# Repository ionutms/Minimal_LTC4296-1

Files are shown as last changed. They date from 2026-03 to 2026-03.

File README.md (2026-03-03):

# Minimal_LTC4296-1

## Overview

This repository contains a minimal KiCad design project for the Analog Devices LTC4296-1, a 5-port SPoE (Single-Pair Power over Ethernet) PSE (Power Sourcing Equipment) controller. The project includes schematic designs and PCB layout files for implementing this versatile multi-port PoE controller.

## Disclaimer

> [!NOTE]
> This project is provided "as is" and without any warranty, express or implied. For more details, please see the [LICENSE](LICENSE) file.

## About the LTC4296-1

The LTC4296-1 from Analog Devices is a 5-port SPoE (Single-Pair Power over Ethernet) PSE controller designed for building and factory automation applications. It provides power sourcing equipment functionality for IEEE 802.3cg-compliant single-pair Ethernet systems.

Key features include:

- **5 Independent PSE Ports:** Controls up to five independent PSE ports with individual monitoring and control.
- **Wide Input Supply Range:** Operates from 6 V to 60 V, supporting both 24 V and 54 V systems.
- **IEEE 802.3cg Compliant:** Supports Single-Pair Power over Ethernet (SPoE) standard with power classes 10 through 15.
- **SCCP Support:** Supports Serial Communication Classification Protocol (SCCP) with external microcontroller for PD classification.
- **SPI Interface:** SPI bus interface with PEC (Packet Error Code) protection for digital control and monitoring.
- **Advanced Protection:** Features adjustable source and return electronic circuit breakers, high-side circuit breakers with foldback, and analog current limit (ACL).
- **Low Power Consumption:** Ultra-low input supply current of 52 μA (typ) in sleep state and 51 μA (typ) in disabled state.
- **Telemetry:** Voltage, current, and temperature telemetry with per-port power-good comparators.
- **Operating Temperature Range:** -40°C to +125°C.
- **Package:** Available in a 48-lead plastic QFN package (7 mm × 7 mm).

## Project Structure

```
minimal_ltc4296-1/
├── minimal_ltc4296-1.kicad_pro                     # Project configuration file
├── minimal_ltc4296-1.kicad_sch                     # Main schematic file
├── SCCP Circuit 0.kicad_sch                        # SCCP circuit schematic
├── minimal_ltc4296-1.kicad_pcb                     # PCB layout file
├── fp-lib-table                                    # Footprint library table
├── sym-lib-table                                   # Symbol library table
├── docs/                                           # Documentation files
│   ├── bom/                                        # Bill of Materials
│   │   └── minimal_ltc4296-1_ibom.html             # Interactive BOM file
│   ├── pictures/                                   # Images and photos
│   │   ├── 1_minimal_ltc4296-1_side.png            # Side view of PCB
│   │   ├── 2_minimal_ltc4296-1_top.png             # Top view of PCB
│   │   ├── 3_minimal_ltc4296-1_bottom.png          # Bottom view of PCB
│   │   ├── 4_minimal_ltc4296-1_left.png            # Left view of PCB
│   │   ├── 5_minimal_ltc4296-1_right.png           # Right view of PCB
│   │   ├── 6_minimal_ltc4296-1_front.png           # Front view of PCB
│   │   ├── 7_minimal_ltc4296-1_back.png            # Back view of PCB
│   │   └── 8_minimal_ltc4296-1_test.png            # Test view of PCB
│   └── schematics/                                 # Schematic PDF exports
│       └── minimal_ltc4296-1_schematics.pdf        # Complete schematics PDF
└── KiCAD_Symbols_Generator/                        # Submodule for symbol generation from CSV data
```

## Project Features

This design provides a minimal implementation of the LTC4296-1 with:

- 5-port PSE controller configuration
- SPI interface for digital control
- SCCP classification support
- Per-port current monitoring and protection
- Standard footprint for the 48-lead QFN package

## Getting Started

### Prerequisites

- [KiCad EDA](https://www.kicad.org/) version 9.0 or later installed on your system
- Git (for cloning the repository and submodule management)

### Opening the Project

1. **Clone the repository** (including submodules):
   ```bash
   git clone --recursive https://github.com/ionutms/Minimal_LTC4296-1.git
   ```

   If you've already cloned the repository without submodules, initialize them with:
   ```bash
   git submodule init
   git submodule update
   ```

2. **Open the project in KiCad**:
   - Launch KiCad
   - Click "Open Existing Project"
   - Navigate to the cloned repository folder
   - Select the `minimal_ltc4296-1.kicad_pro` file

3. **Explore the design**:
   - Open the schematic editor to view the circuit design
   - Open the PCB editor to view the board layout
   - Review the symbol and footprint libraries used in the design

### Project Files

- **Main schematic**: `minimal_ltc4296-1.kicad_sch` - Contains the primary circuit design with the LTC4296-1 and support components
- **SCCP schematic**: `SCCP Circuit 0.kicad_sch` - SCCP circuit implementation for PD classification
- **PCB layout**: `minimal_ltc4296-1.kicad_pcb` - Physical board design file with proper component placement
- **Project configuration**: `minimal_ltc4296-1.kicad_pro` - KiCad project settings

## Dependencies

This project has the following dependencies:

### 1. KiCAD Symbols Generator

This repository uses [KiCAD_Symbols_Generator](https://github.com/ionutms/KiCAD_Symbols_Generator) as a submodule for custom symbol generation.

To initialize the submodule after cloning this repository:

```bash
git submodule update --init --recursive
```

### 2. 3D Models

This project requires the [3D_Models_Vault](https://github.com/ionutms/3D_Models_Vault) repository for 3D models.

#### Setup for KiCAD 9:

1. Clone the 3D models repository:
   ```bash
   git clone https://github.com/ionutms/3D_Models_Vault.git
   ```

2. In KiCAD 9, add an environment variable:
   - Variable name: `KICAD9_3D_MODELS_VAULT`
   - Variable value: Full path to where you cloned the 3D_Models_Vault repository

## Usage

After setting up the dependencies, open the project in KiCad 9 to access all features including the 3D models.

## Symbol Generator Submodule

This project includes the KiCAD_Symbols_Generator as a submodule, which provides tools for generating KiCad symbols from CSV data files. For more information on using this tool, see the [KiCAD_Symbols_Generator documentation](minimal_ltc4296-1/KiCAD_Symbols_Generator/README.md).

## Documentation

The `docs` folder contains:
- Schematic PDF exports
- Images and photos of the design

## Visuals

The following images showcase the PCB design from different perspectives:

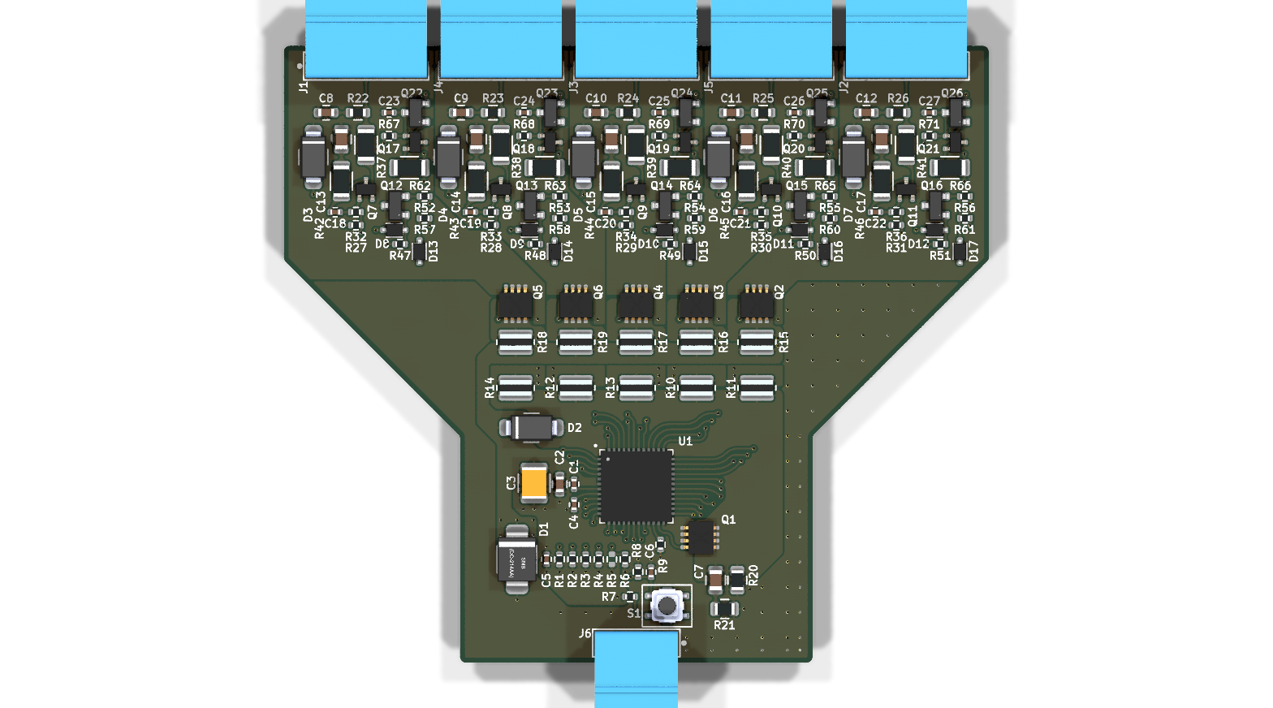
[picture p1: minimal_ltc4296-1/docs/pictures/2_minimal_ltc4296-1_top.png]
Top View

*Top View of the PCB*

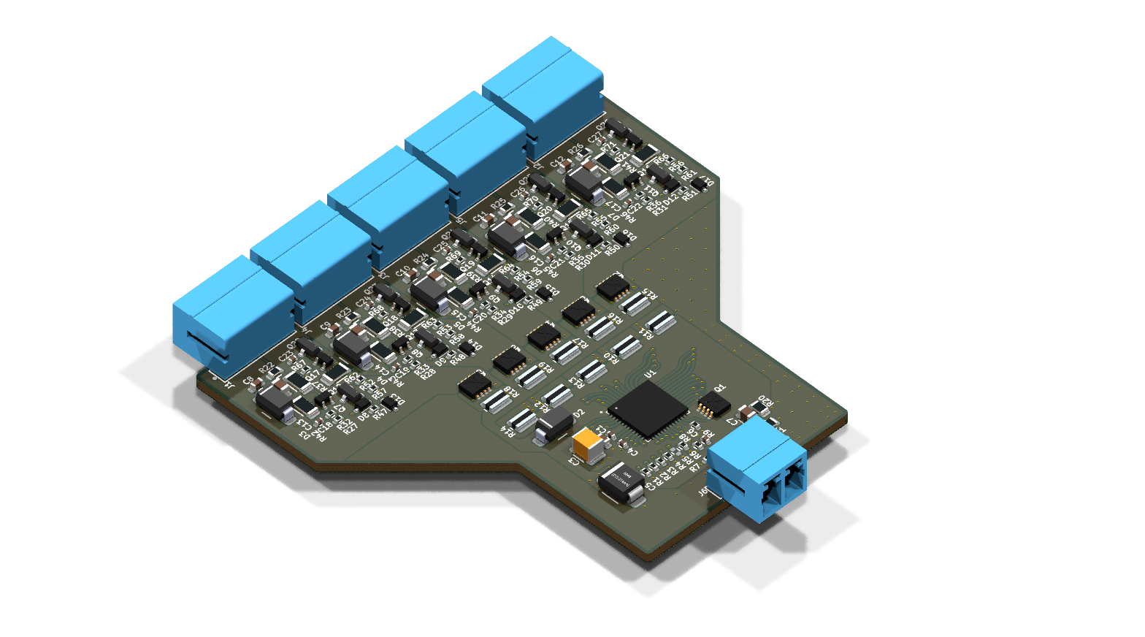
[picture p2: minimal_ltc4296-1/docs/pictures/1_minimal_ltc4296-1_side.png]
Side View

*Side View of the PCB*

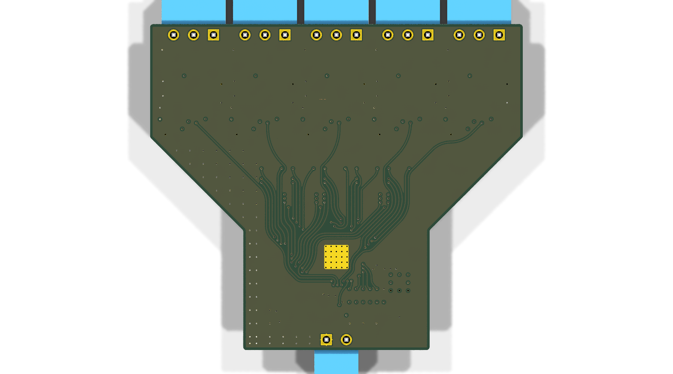
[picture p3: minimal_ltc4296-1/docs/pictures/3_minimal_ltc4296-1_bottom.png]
Bottom View

*Bottom View of the PCB*

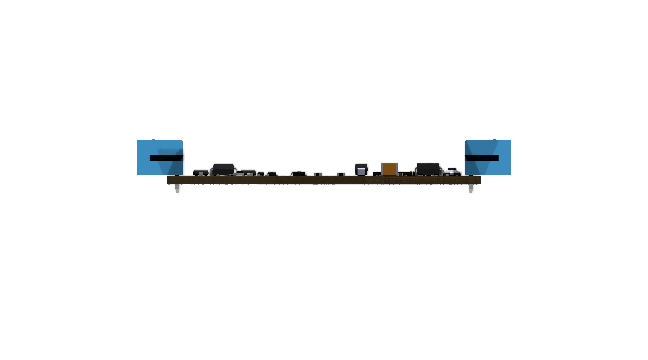
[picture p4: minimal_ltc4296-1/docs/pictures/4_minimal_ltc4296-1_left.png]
Left View

*Left View of the PCB*

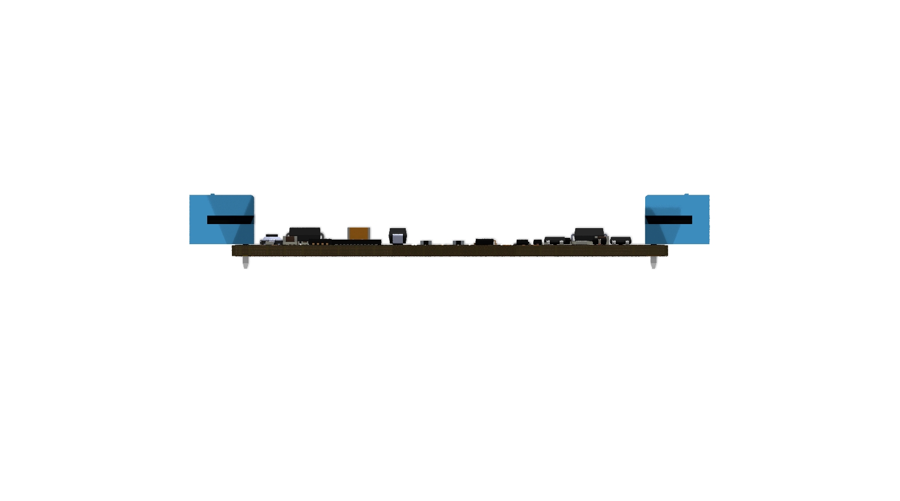
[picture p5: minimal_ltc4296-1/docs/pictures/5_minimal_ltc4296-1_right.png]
Right View

*Right View of the PCB*

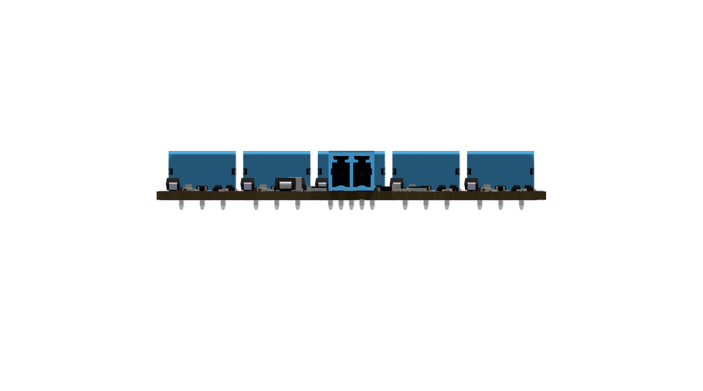
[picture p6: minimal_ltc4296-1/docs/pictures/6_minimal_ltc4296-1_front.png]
Front View

*Front View of the PCB*

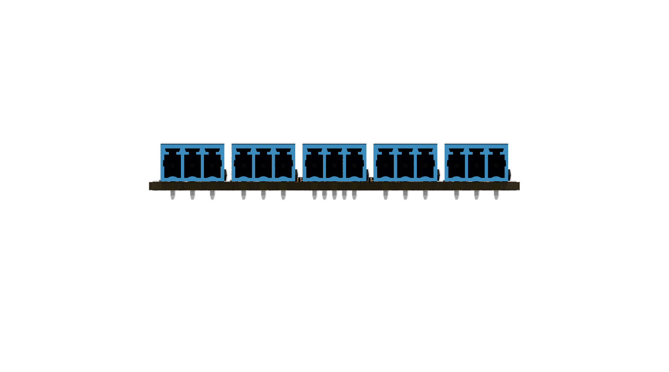
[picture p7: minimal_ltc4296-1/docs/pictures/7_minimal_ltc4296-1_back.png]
Back View

*Back View of the PCB*

## License

This project is licensed under the MIT License - see the [LICENSE](LICENSE) file for details.

## References

- [LTC4296-1 Datasheet](https://www.analog.com/media/en/technical-documentation/data-sheets/ltc4296-1.pdf)
- [LTC4296-1 Product Page](https://www.analog.com/en/products/ltc4296-1.html)
- [KiCad EDA](https://www.kicad.org/)

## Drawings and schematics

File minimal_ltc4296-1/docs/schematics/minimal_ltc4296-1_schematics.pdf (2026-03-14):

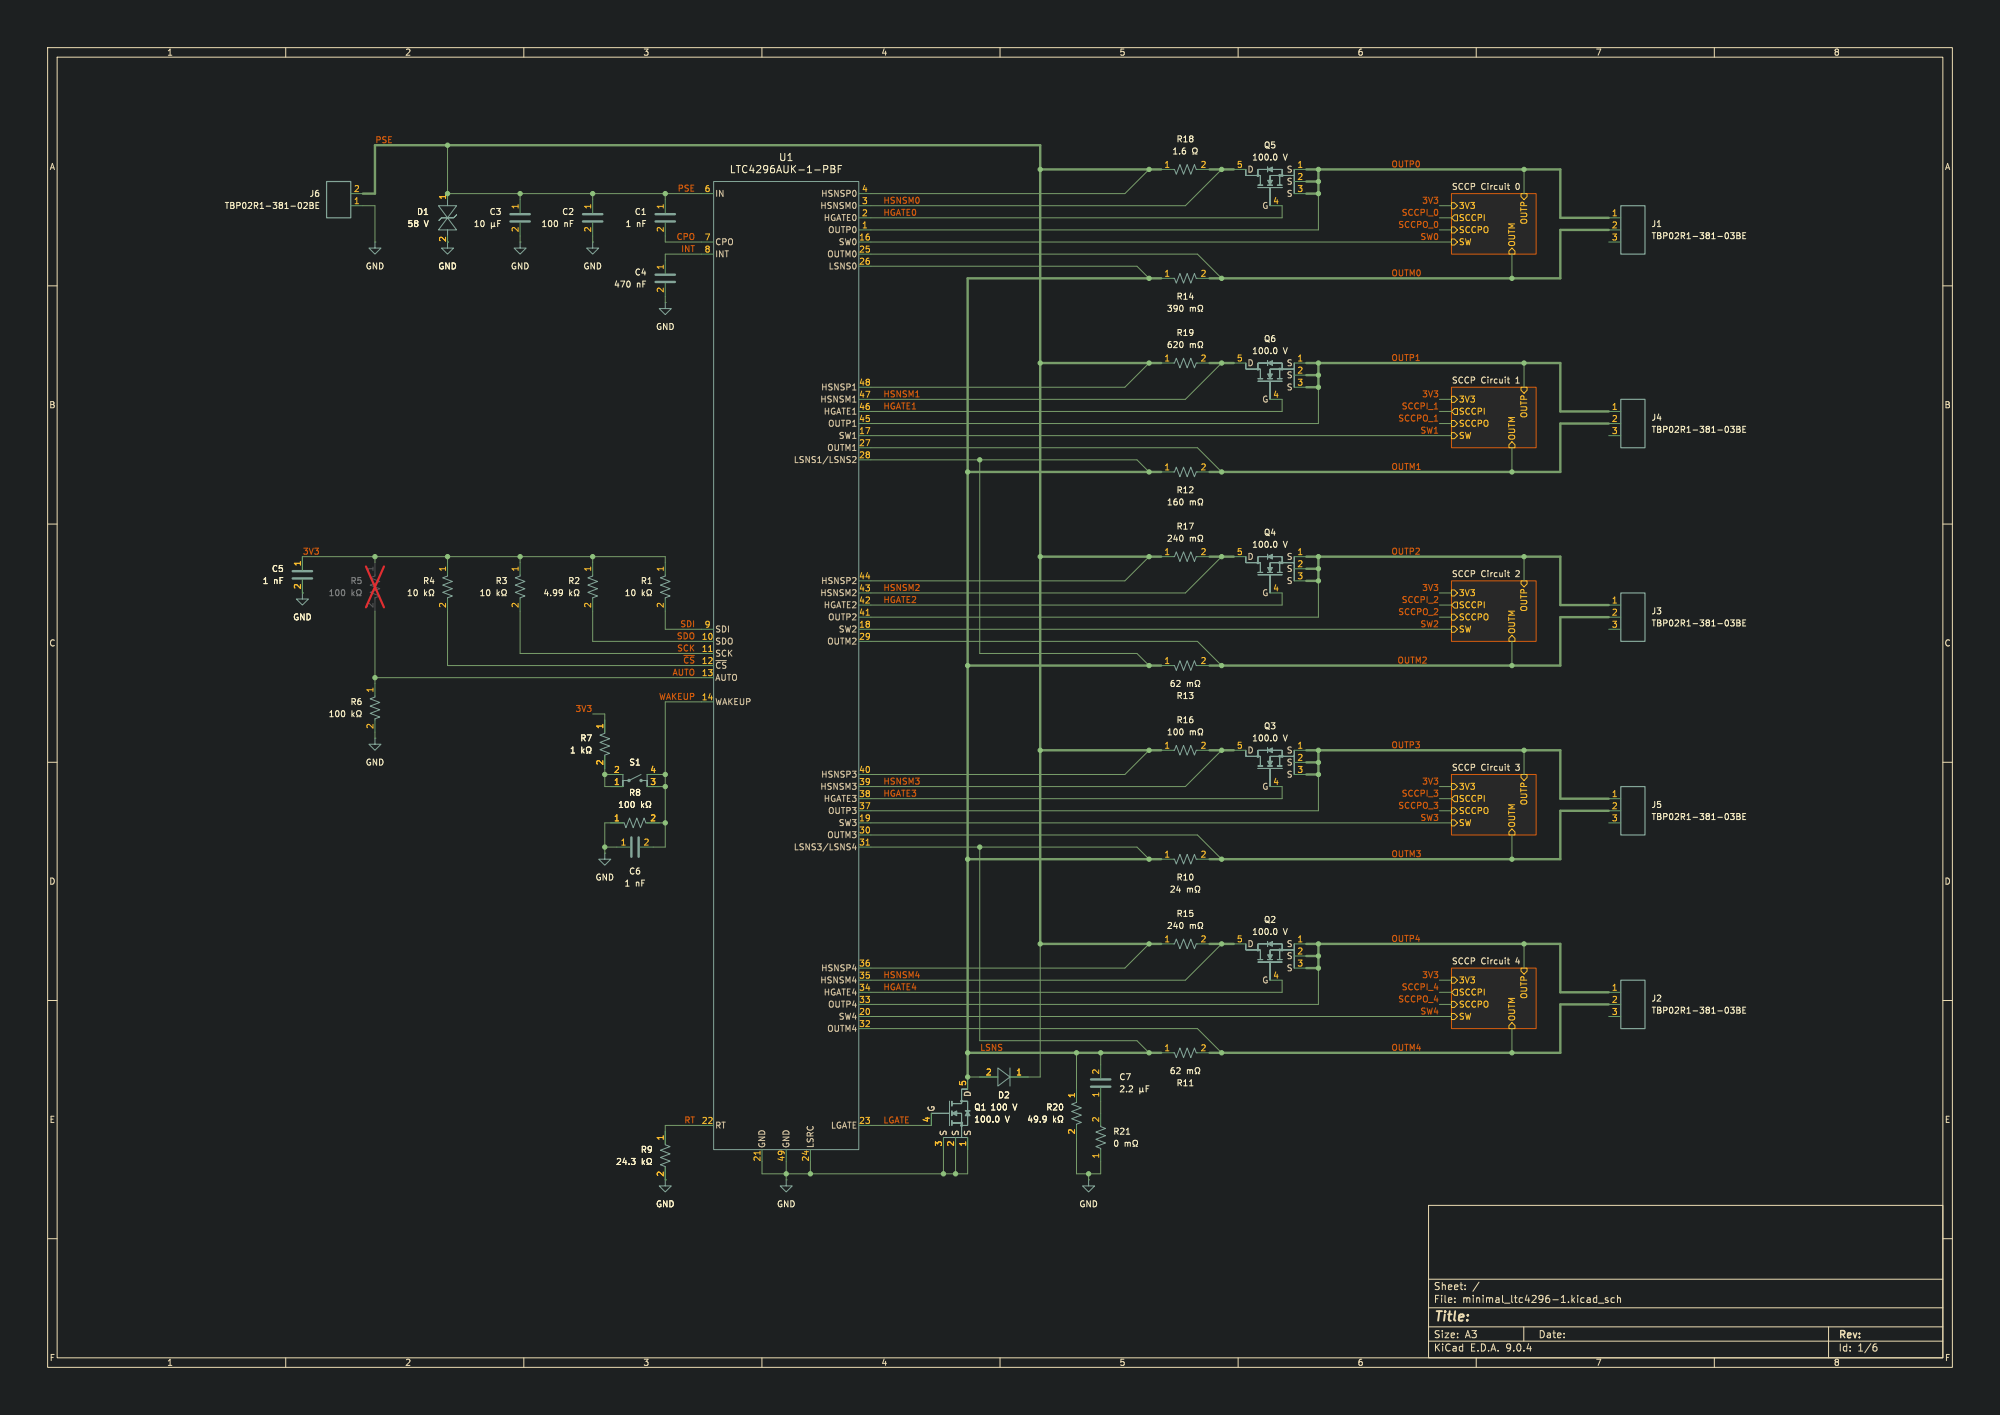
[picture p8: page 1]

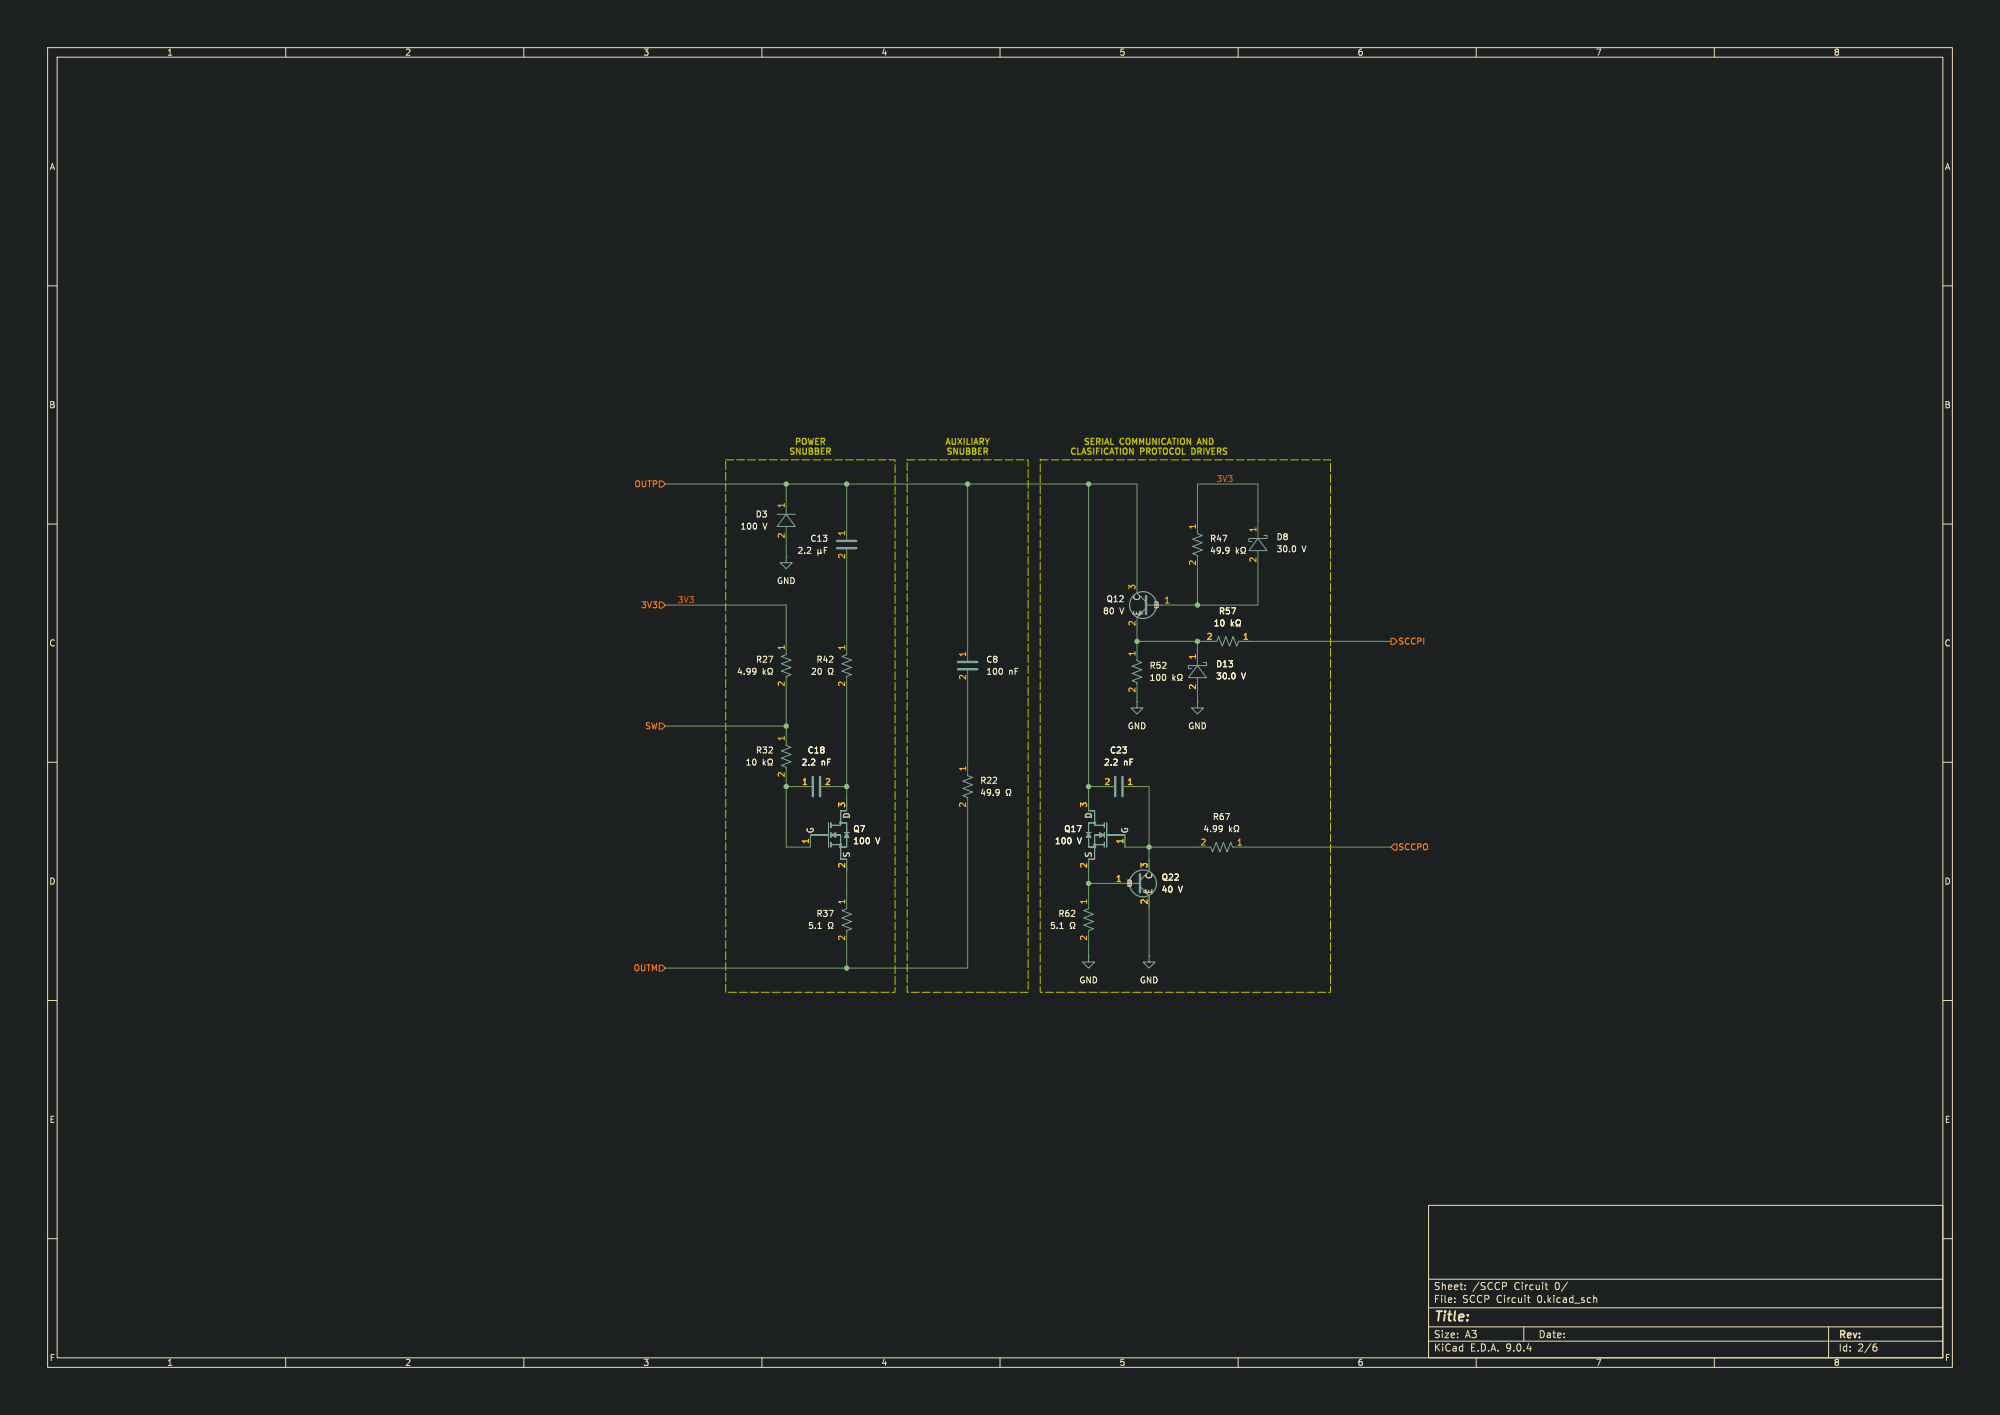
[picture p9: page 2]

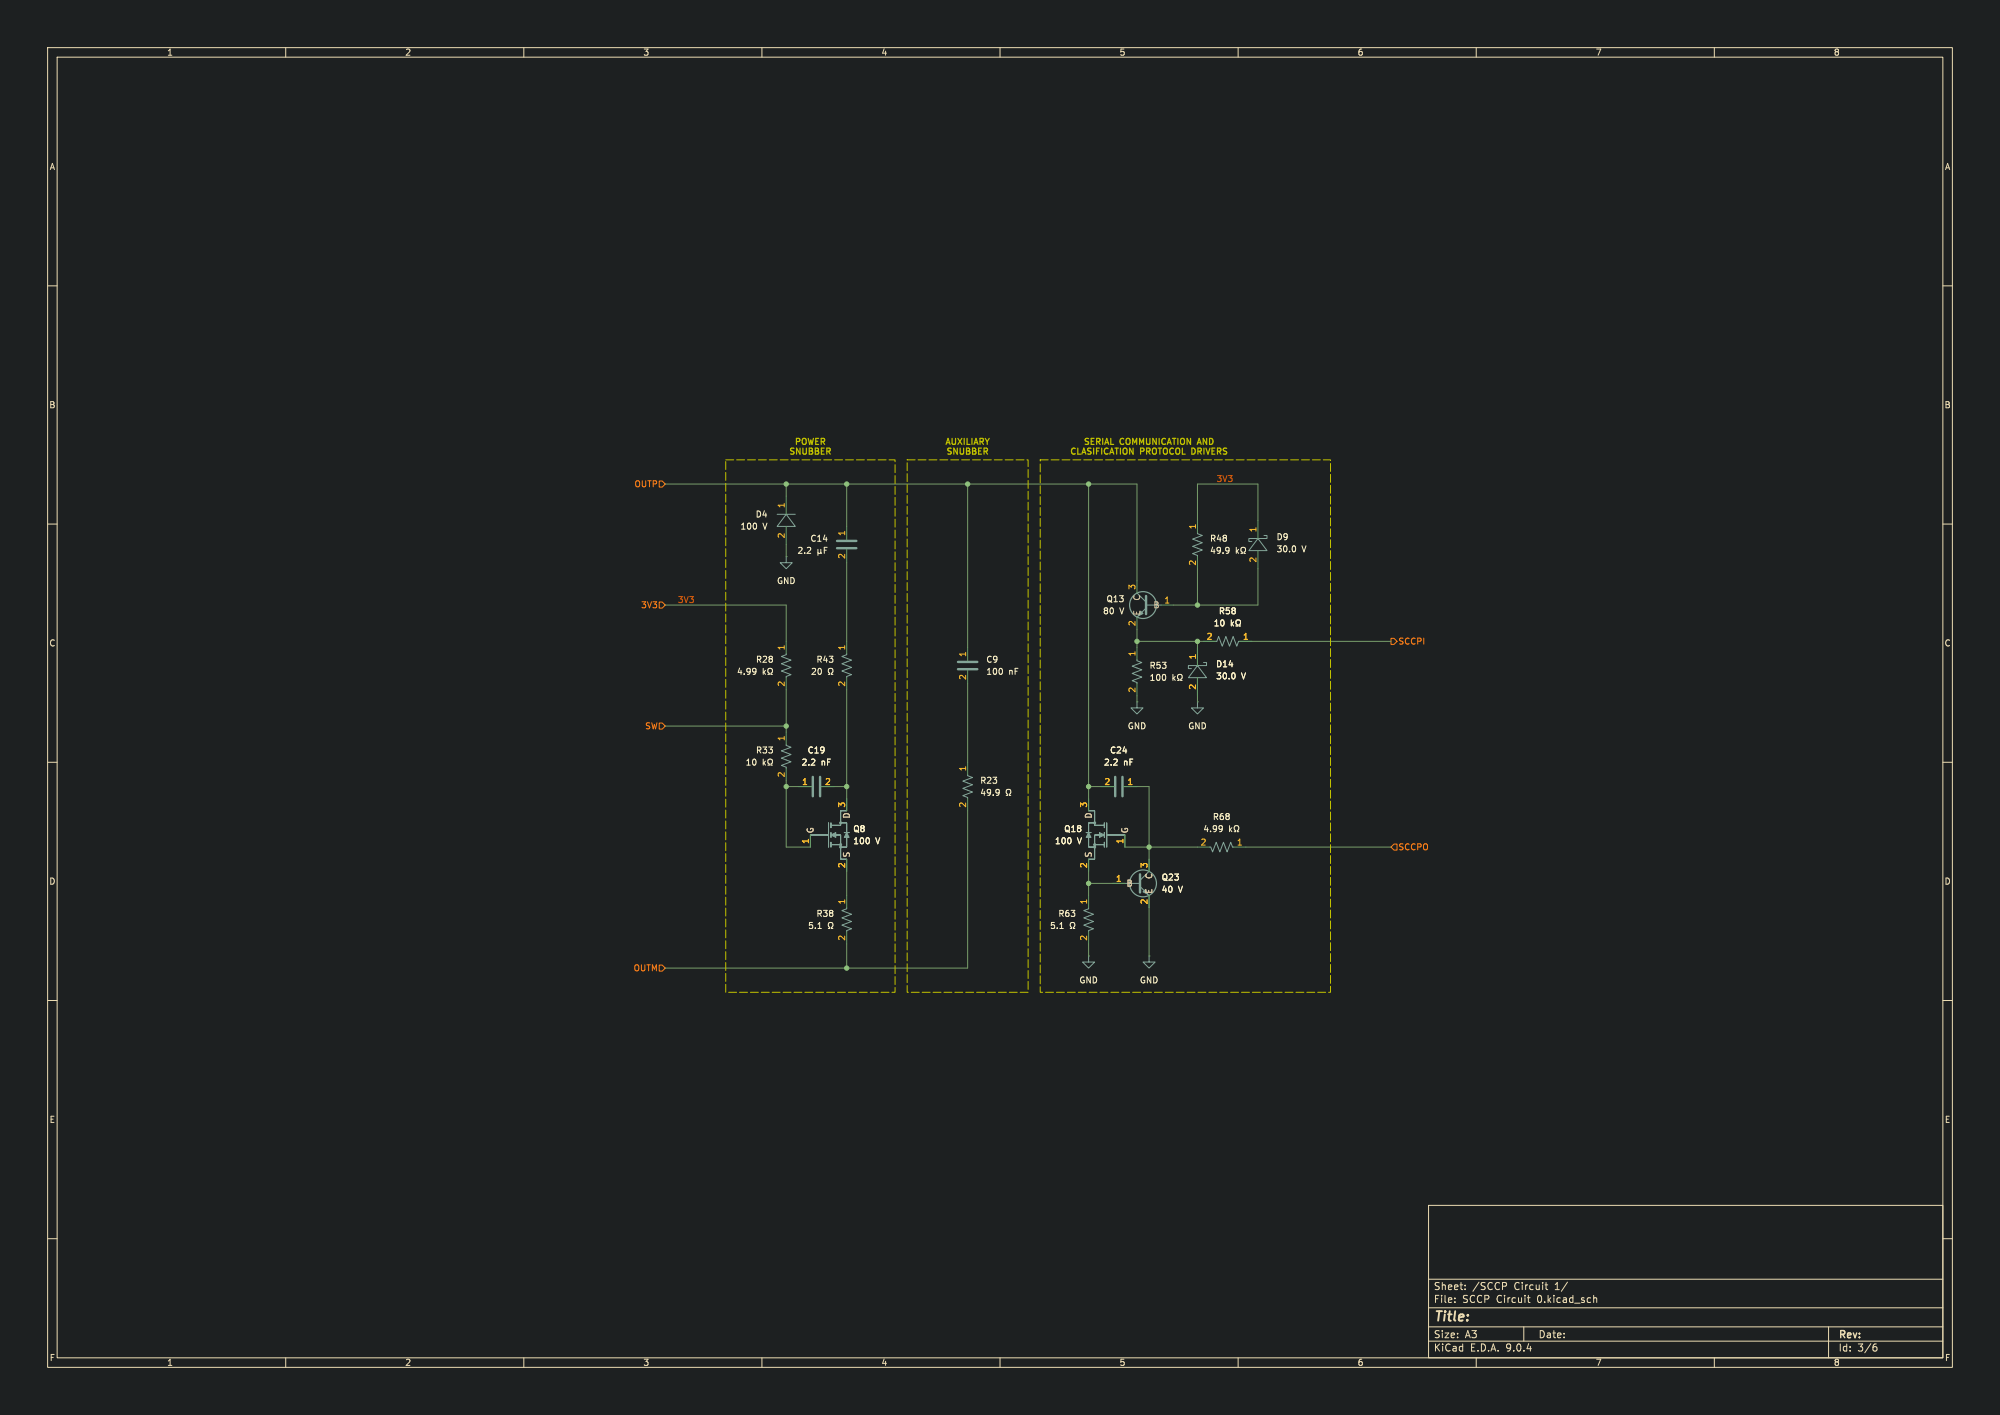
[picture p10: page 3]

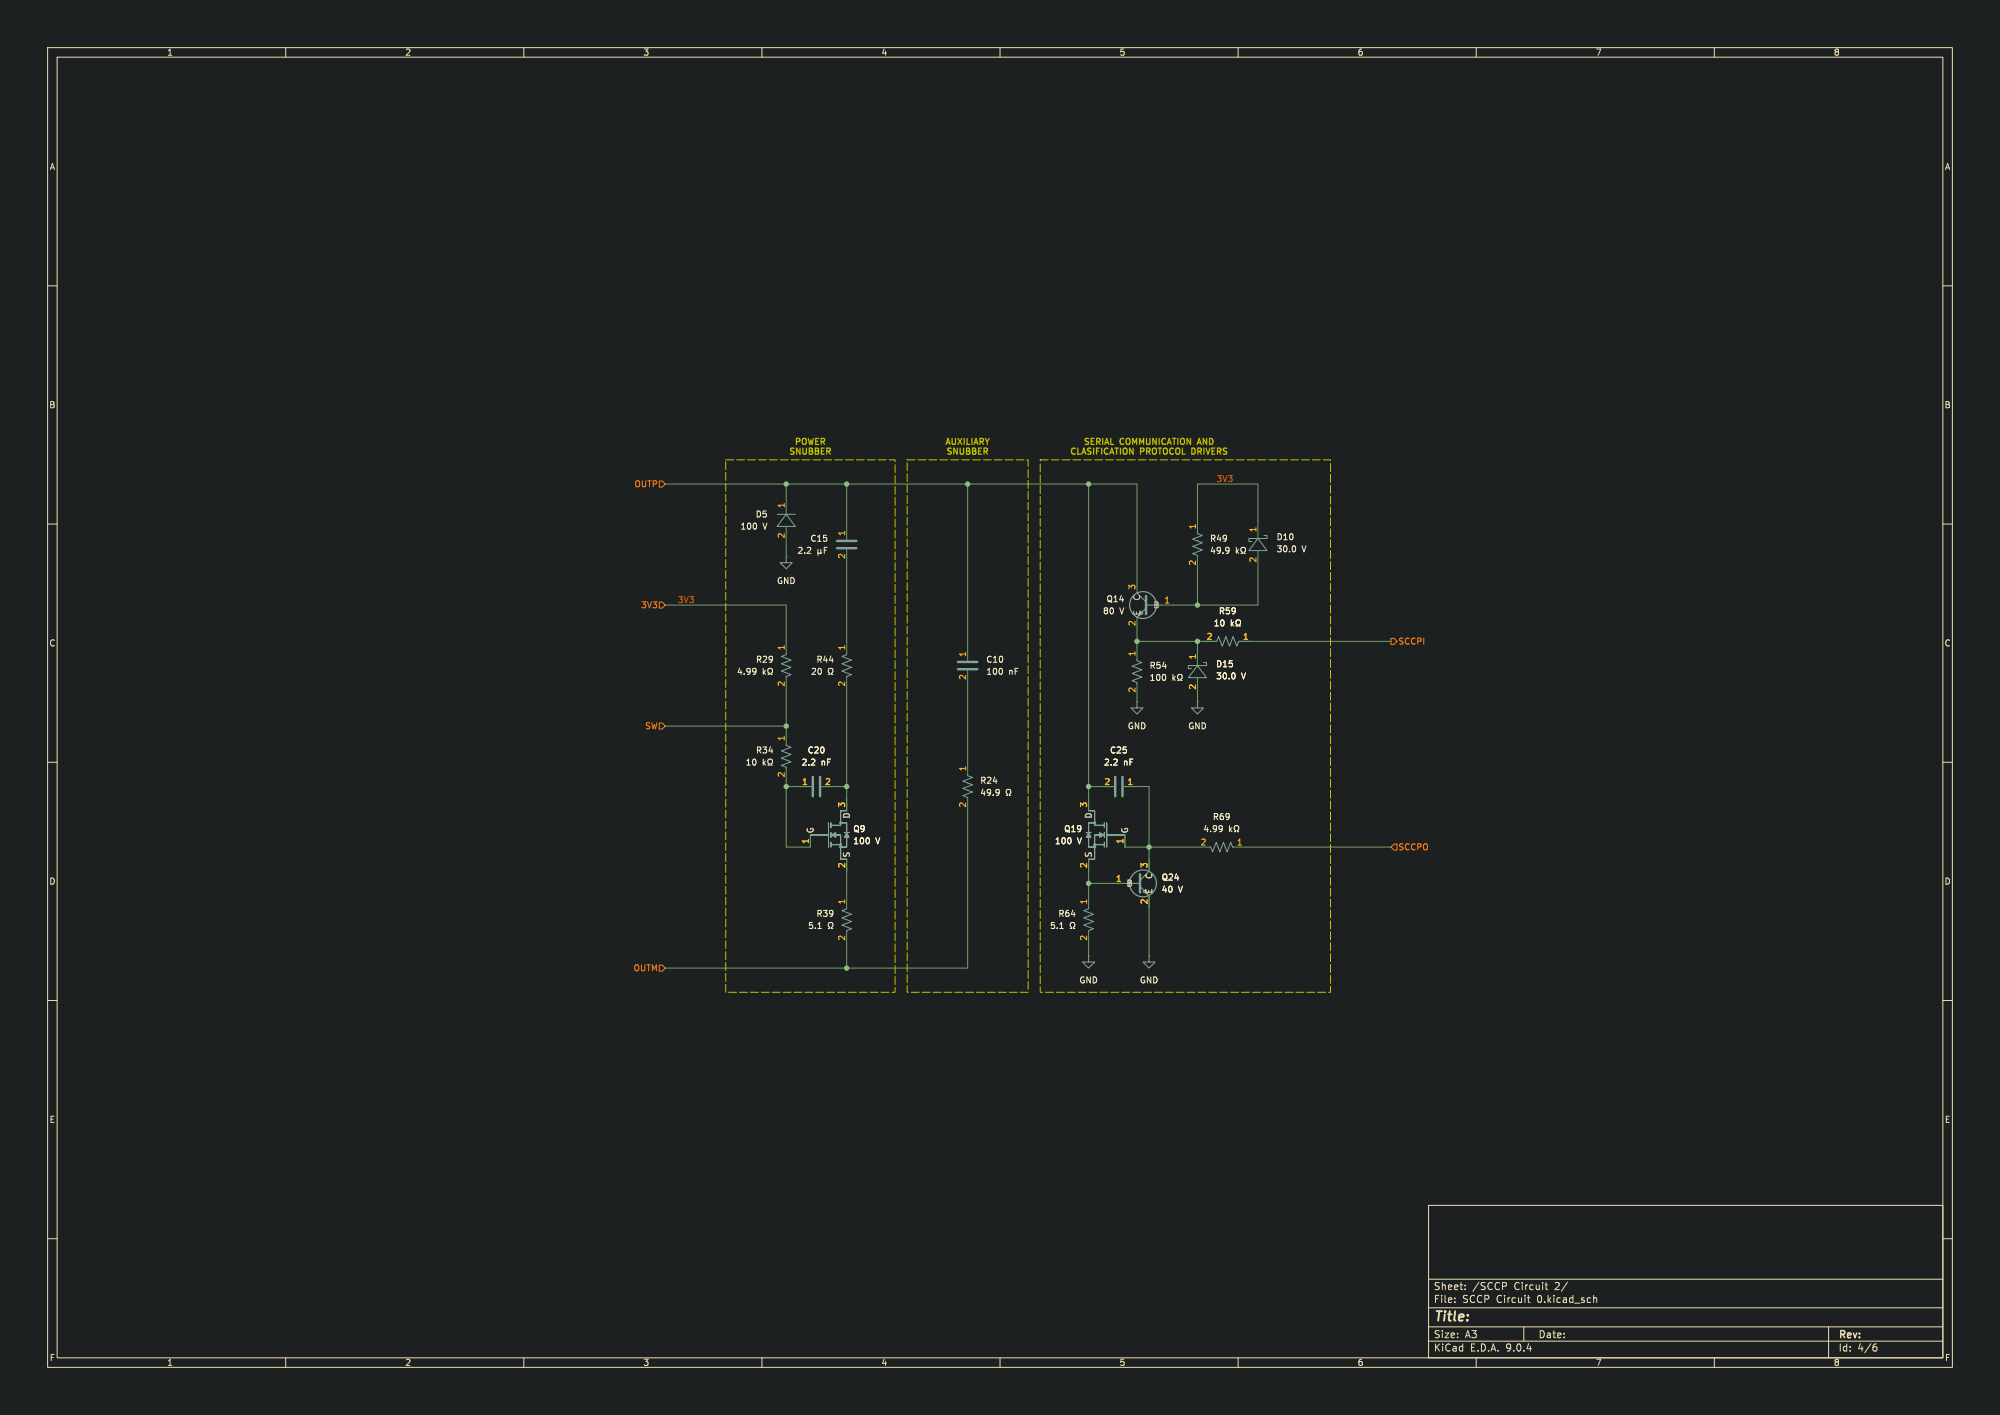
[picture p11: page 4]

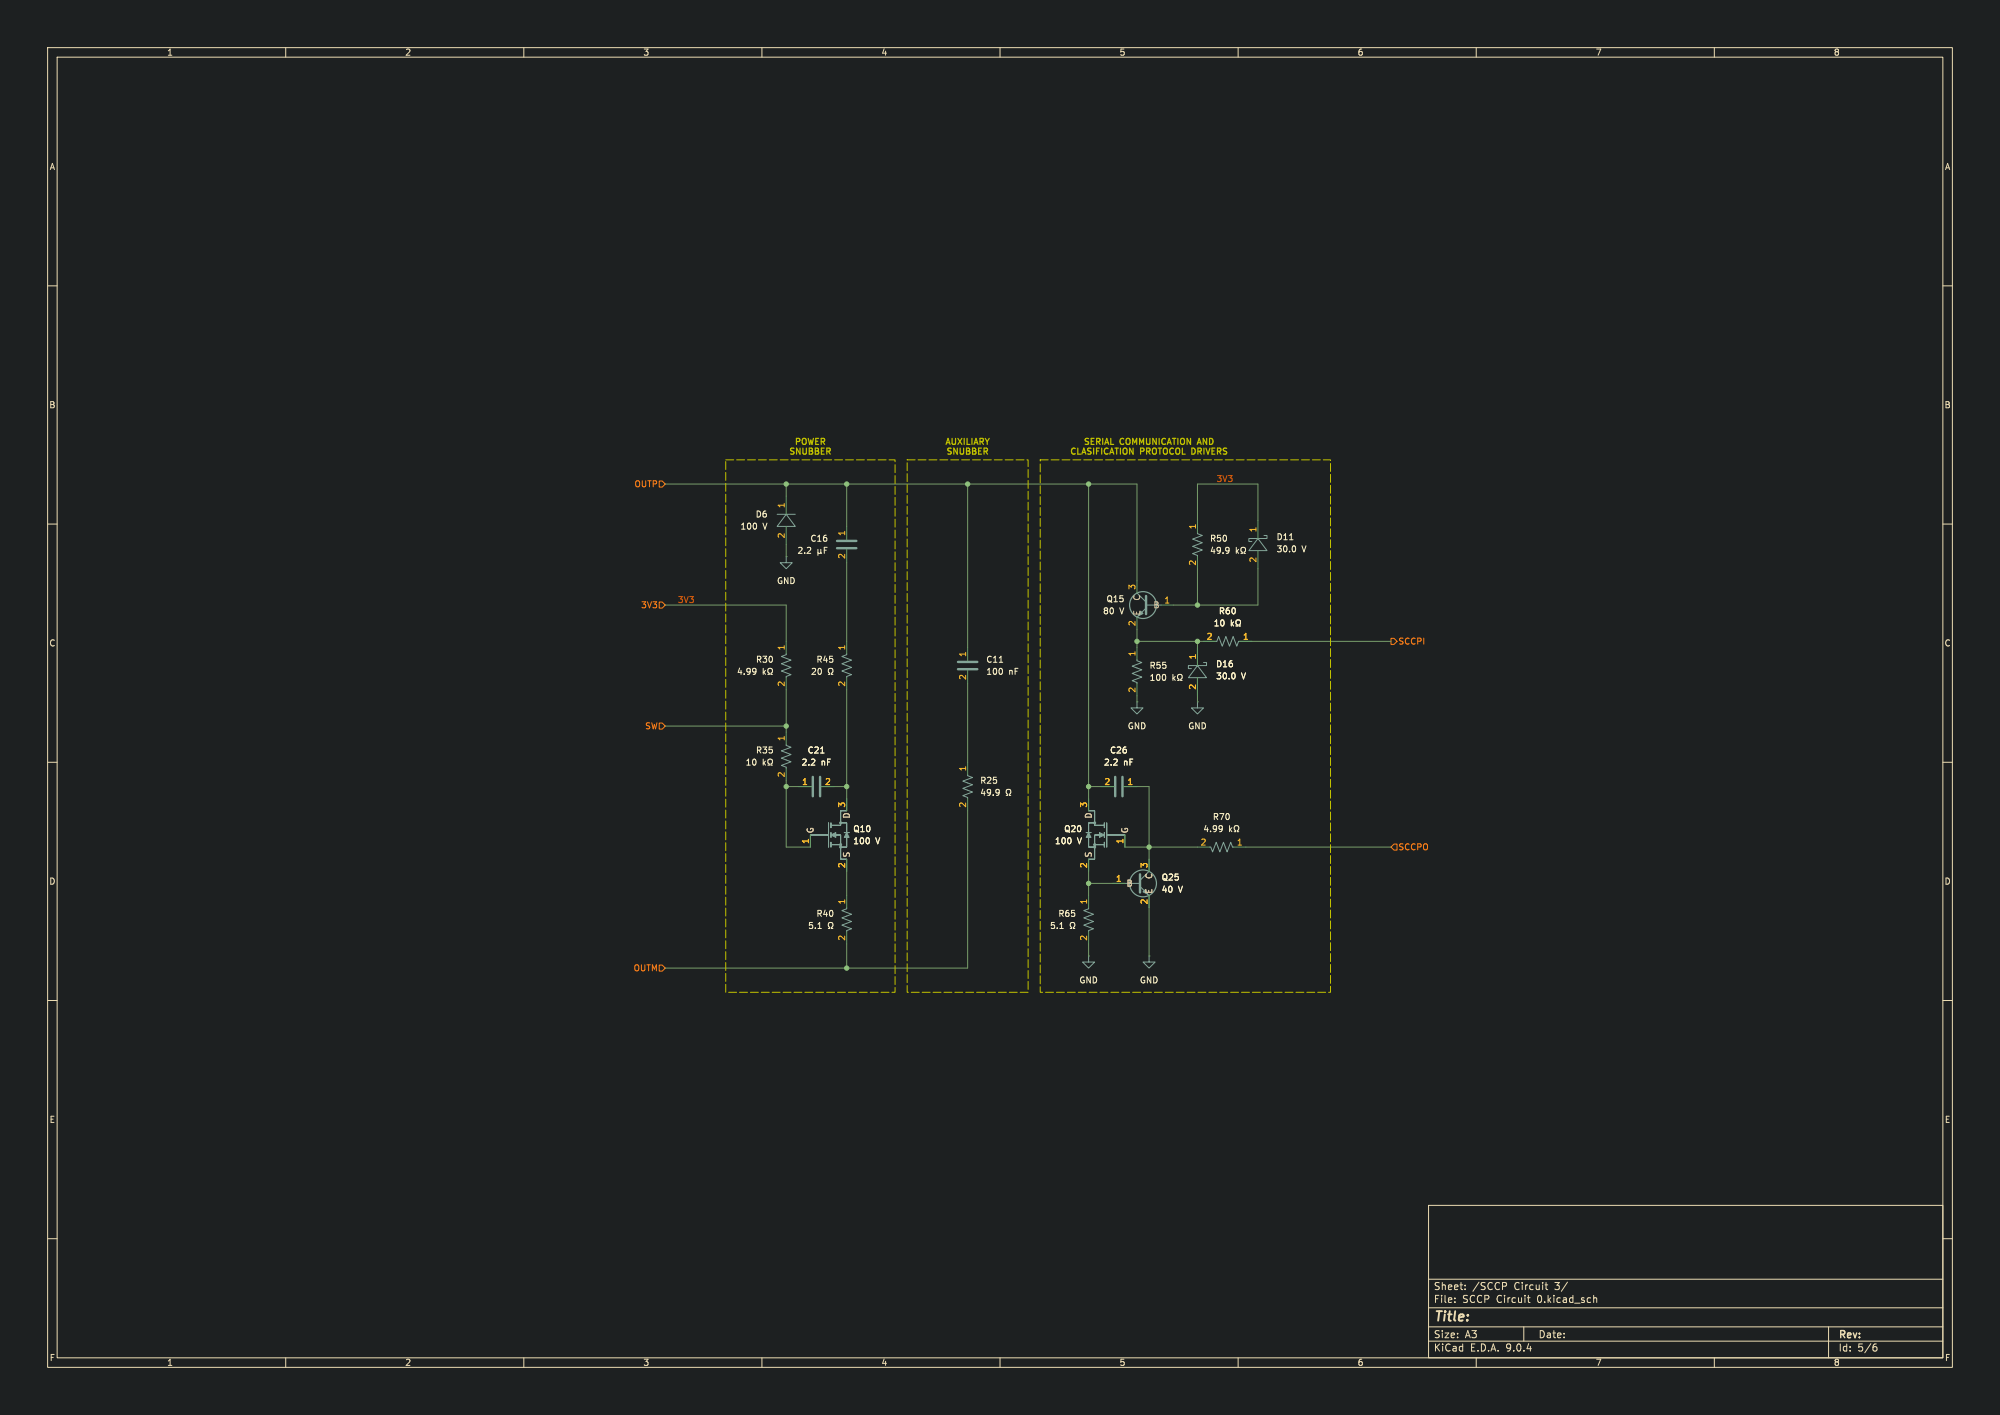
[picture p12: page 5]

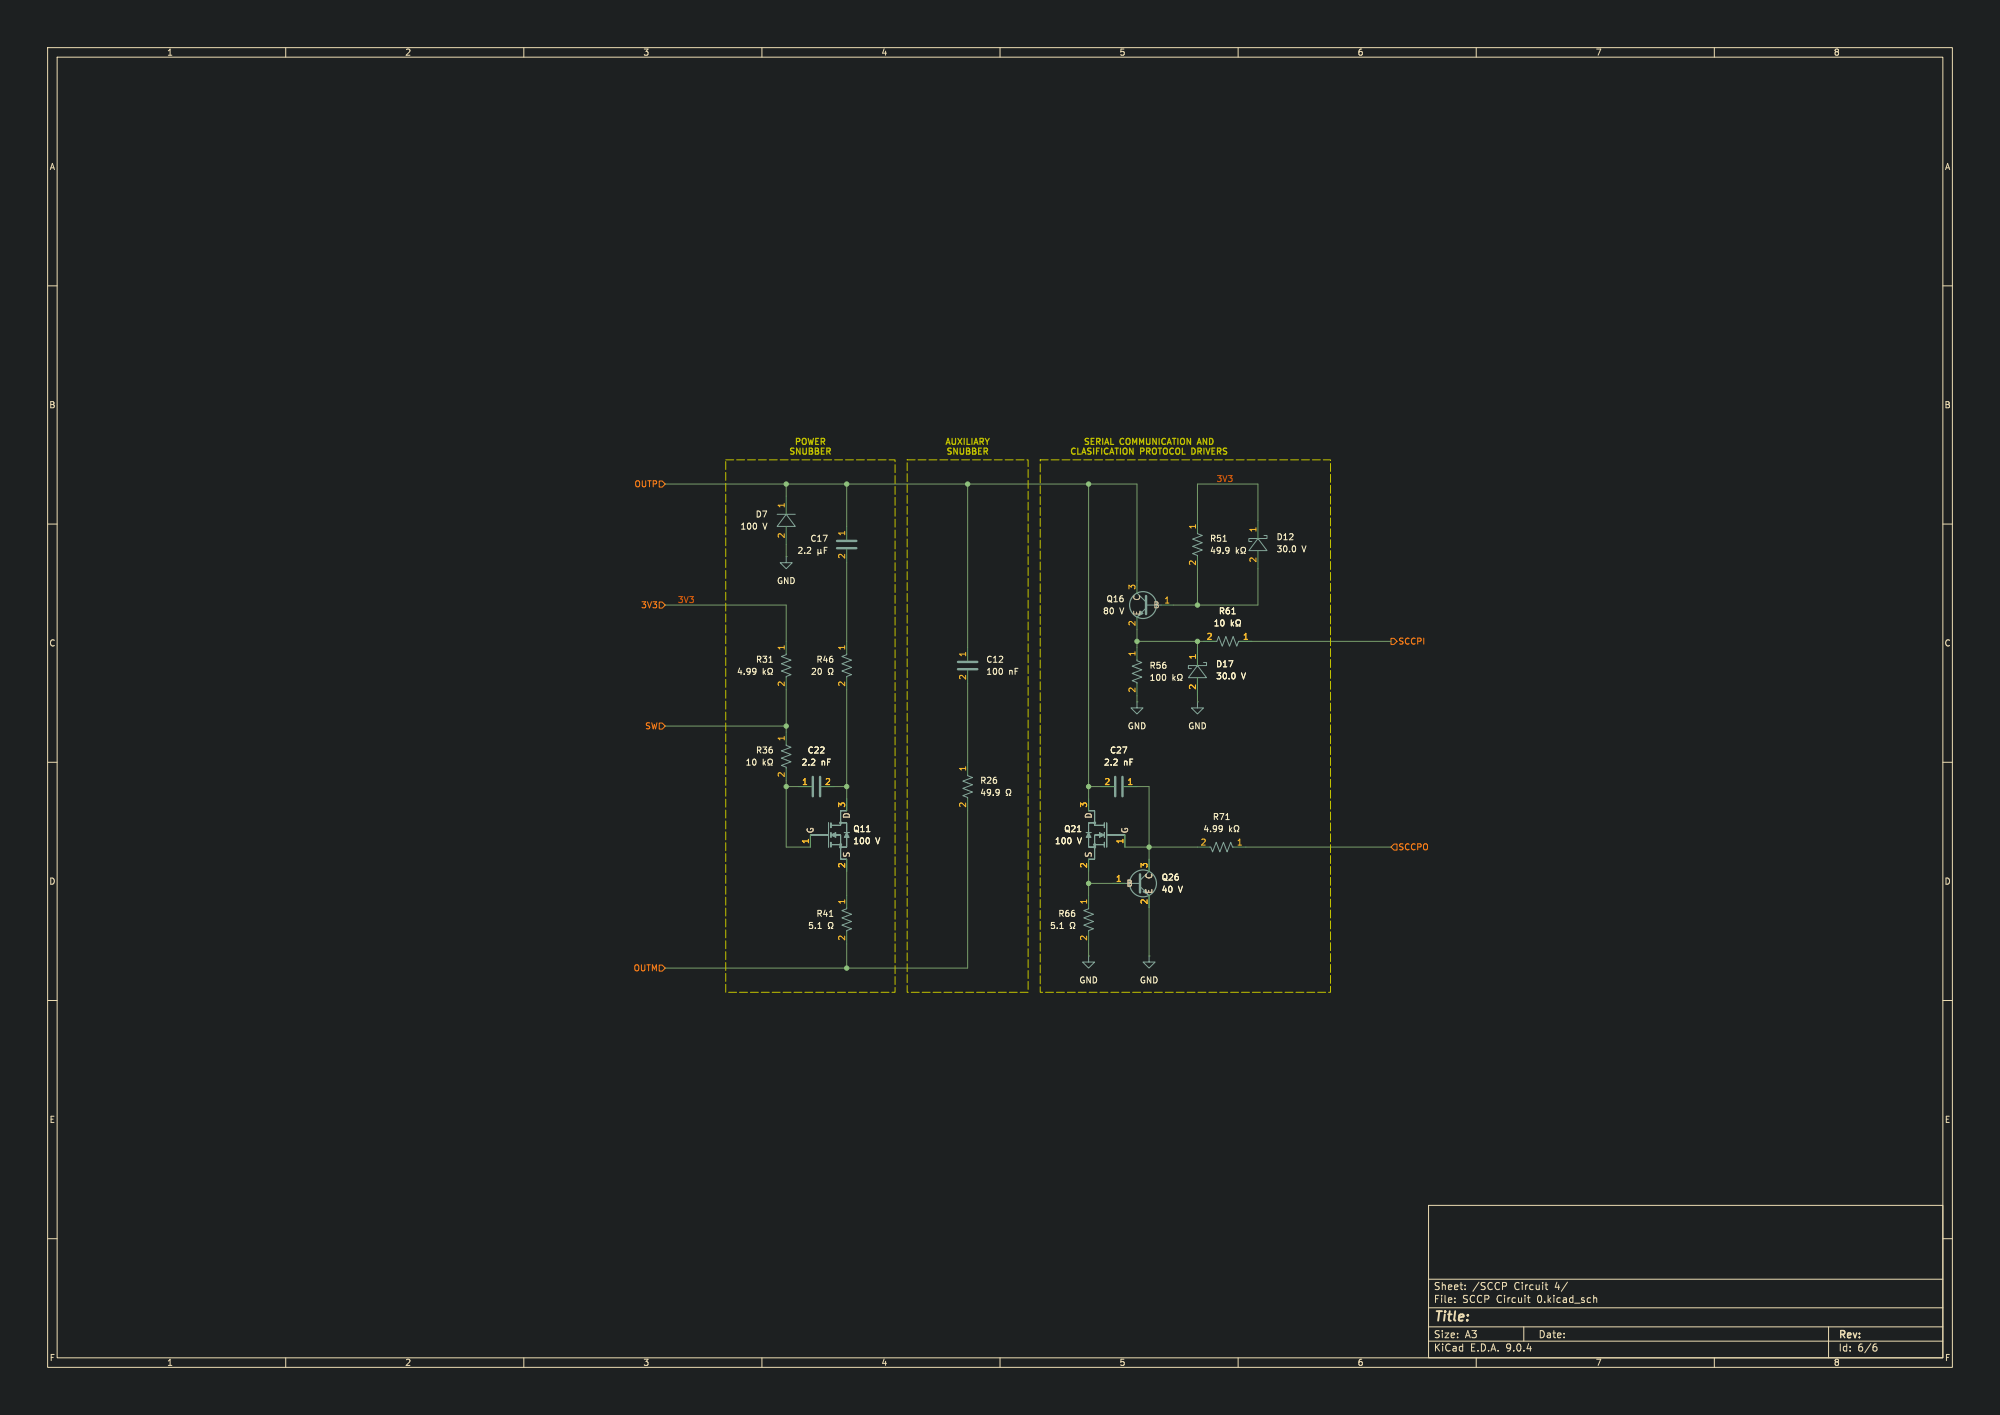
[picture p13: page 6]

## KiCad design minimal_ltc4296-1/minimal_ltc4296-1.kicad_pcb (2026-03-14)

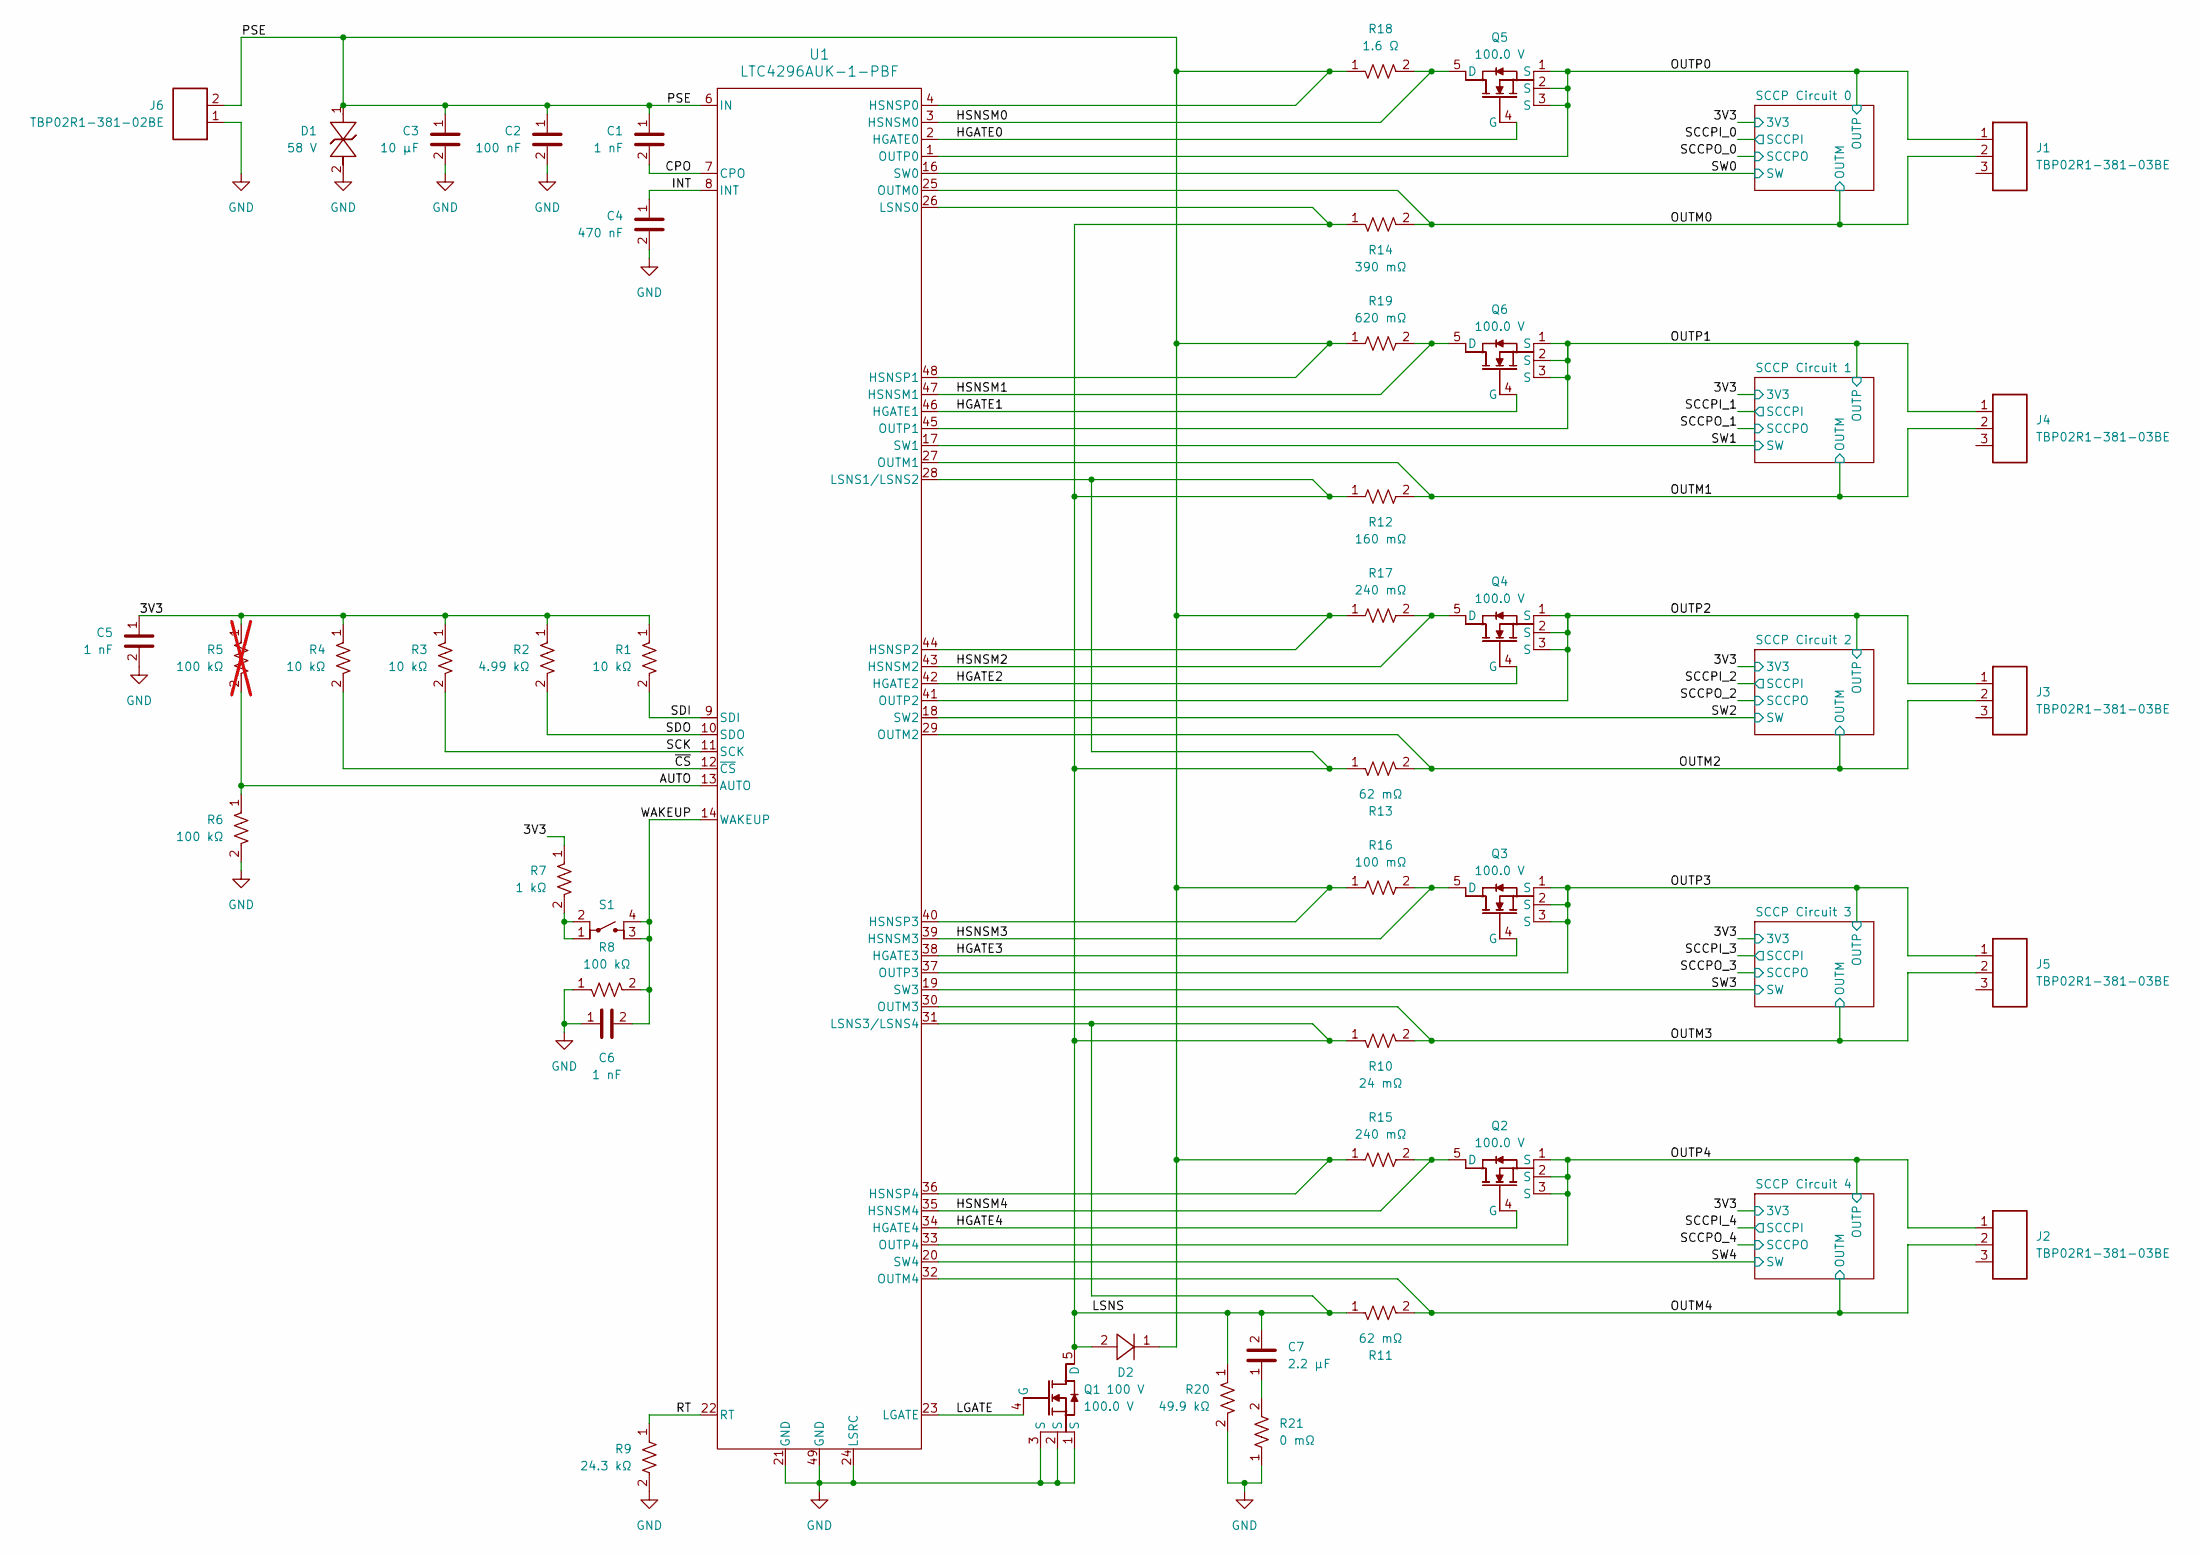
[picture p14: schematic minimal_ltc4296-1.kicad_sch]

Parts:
C1: 1 nF; C_0402_1005Metric; Tolerance 10%; Voltage Rating 100V; MPN C1005X7S2A102K050BB
C2: 100 nF; C_0603_1608Metric; Tolerance 10%; Voltage Rating 100V; MPN C1608X7S2A104K080AB
C3: 10 µF; C_1210_250_3225Metric; Tolerance 10%; Voltage Rating 100V; MPN GRM32EC72A106KE05L
C4: 470 nF; C_0402_1005Metric; Tolerance 10%; Voltage Rating 25V; MPN C1005X5R1E474K050BB
C5, C6: 1 nF; C_0402_1005Metric; Tolerance 10%; Voltage Rating 50V; MPN GCM155R71H102KA37D
C7: 2.2 µF; C_0805_2012Metric; Tolerance 10%; Voltage Rating 100V; MPN CGA4J1X7R2A225K125AC
D1: 58 V; DO-214AA; MPN SMBJ58CA
D2: 100 V; SMA; MPN S1B-13-F
J1, J2, J3, J4, J5: TBP02R1-381-03BE; Current Rating (A) 8.0; Voltage Rating (V) 300; MPN TBP02R1-381-03BE
J6: TBP02R1-381-02BE; Current Rating (A) 8.0; Voltage Rating (V) 300; MPN TBP02R1-381-02BE
Q1, Q2, Q4, Q5: 100.0 V; LFPAK33-8; MPN PSMN075-100MSEX
Q3, Q6: 100.0 V; LFPAK33-8; MPN PSMN040-100MSEX
R1, R3, R4: 10 kΩ; R_0402_1005Metric; Tolerance 1%; Voltage Rating 50V; MPN ERJ-2RKF1002X
R2: 4.99 kΩ; R_0402_1005Metric; Tolerance 1%; Voltage Rating 50V; MPN ERJ-2RKF4991X
R5: 100 kΩ; R_0402_1005Metric; Tolerance 1%; Voltage Rating 50V; MPN ERJ-2RKF1003X; not fitted
R6, R8: 100 kΩ; R_0402_1005Metric; Tolerance 1%; Voltage Rating 50V; MPN ERJ-2RKF1003X
R7: 1 kΩ; R_0402_1005Metric; Tolerance 1%; Voltage Rating 50V; MPN ERJ-2RKF1001X
R9: 24.3 kΩ; R_0402_1005Metric; Tolerance 1%; Voltage Rating 50V; MPN ERJ-2RKF2432X
R10: 24 mΩ; R_0612_1632Metric; Tolerance 1%; MPN ERJ-B2CFR024V
R11, R13: 62 mΩ; R_0612_1632Metric; Tolerance 1%; MPN PRL1632-R062-F-T1
R12: 160 mΩ; R_0612_1632Metric; Tolerance 1%; MPN ERJ-B2CFR16V
R14: 390 mΩ; R_0612_1632Metric; Tolerance 1%; MPN ERJ-B2BFR39V
R15, R17: 240 mΩ; R_0612_1632Metric; Tolerance 1%; MPN ERJ-B2BFR24V
R16: 100 mΩ; R_0612_1632Metric; Tolerance 1%; MPN ERJ-B2CFR10V
R18: 1.6 Ω; R_0612_1632Metric; Tolerance 1%; MPN ERJ-B2BF1R6V
R19: 620 mΩ; R_0612_1632Metric; Tolerance 1%; MPN ERJ-B2BFR62V
R20: 49.9 kΩ; R_0805_2012Metric; Tolerance 1%; Voltage Rating 150V; MPN ERJ-6ENF4992V
R21: 0 mΩ; R_0805_2012Metric; Tolerance 5%; Voltage Rating 150V; MPN ERJ-6GEY0R00V
S1: TS21-34-035-BK-160-SMT-TR; TS21; MPN TS21-34-035-BK-160-SMT-TR
U1: LTC4296AUK-1-PBF; QFN48_05-08-7073_ADI; MPN LTC4296AUK-1-PBF

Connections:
/3V3: C5.1, R1.1, R2.1, R3.1, R4.1, R5.1, R7.1; also elsewhere on the board
/AUTO: R5.2, R6.1, U1.13 (AUTO)
/CPO: C1.2, U1.7 (CPO)
/HGATE0: Q5.4 (G), U1.2 (HGATE0)
/HGATE1: Q6.4 (G), U1.46 (HGATE1)
/HGATE2: Q4.4 (G), U1.42 (HGATE2)
/HGATE3: Q3.4 (G), U1.38 (HGATE3)
/HGATE4: Q2.4 (G), U1.34 (HGATE4)
/HSNSM0: Q5.5 (D), R18.2, U1.3 (HSNSM0)
/HSNSM1: Q6.5 (D), R19.2, U1.47 (HSNSM1)
/HSNSM2: Q4.5 (D), R17.2, U1.43 (HSNSM2)
/HSNSM3: Q3.5 (D), R16.2, U1.39 (HSNSM3)
/HSNSM4: Q2.5 (D), R15.2, U1.35 (HSNSM4)
/INT: C4.1, U1.8 (INT)
/LGATE: Q1.4 (G), U1.23 (LGATE)
/LSNS: C7.2, D2.2, Q1.5 (D), R10.1, R11.1, R12.1, R13.1, R14.1, R20.1, U1.26 (LSNS0), U1.28 (LSNS1/LSNS2), U1.31 (LSNS3/LSNS4)
/OUTM0: J1.2, R14.2, U1.25 (OUTM0); also elsewhere on the board
/OUTM1: J4.2, R12.2, U1.27 (OUTM1); also elsewhere on the board
/OUTM2: J3.2, R13.2, U1.29 (OUTM2); also elsewhere on the board
/OUTM3: J5.2, R10.2, U1.30 (OUTM3); also elsewhere on the board
/OUTM4: J2.2, R11.2, U1.32 (OUTM4); also elsewhere on the board
/OUTP0: J1.1, Q5.1 (S), Q5.2 (S), Q5.3 (S), U1.1 (OUTP0); also elsewhere on the board
/OUTP1: J4.1, Q6.1 (S), Q6.2 (S), Q6.3 (S), U1.45 (OUTP1); also elsewhere on the board
/OUTP2: J3.1, Q4.1 (S), Q4.2 (S), Q4.3 (S), U1.41 (OUTP2); also elsewhere on the board
/OUTP3: J5.1, Q3.1 (S), Q3.2 (S), Q3.3 (S), U1.37 (OUTP3); also elsewhere on the board
/OUTP4: J2.1, Q2.1 (S), Q2.2 (S), Q2.3 (S), U1.33 (OUTP4); also elsewhere on the board
/PSE: C1.1, C2.1, C3.1, D1.1, D2.1, J6.2, R15.1, R16.1, R17.1, R18.1, R19.1, U1.4 (HSNSP0), U1.6 (IN), U1.36 (HSNSP4), U1.40 (HSNSP3), U1.44 (HSNSP2), U1.48 (HSNSP1)
/RT: R9.1, U1.22 (RT)
/SCK: R3.2, U1.11 (SCK)
/SDI: R1.2, U1.9 (SDI)
/SDO: R2.2, U1.10 (SDO)
/SW0: U1.16 (SW0); also elsewhere on the board
/SW1: U1.17 (SW1); also elsewhere on the board
/SW2: U1.18 (SW2); also elsewhere on the board
/SW3: U1.19 (SW3); also elsewhere on the board
/SW4: U1.20 (SW4); also elsewhere on the board
/WAKEUP: C6.2, R8.2, S1.3, S1.4, U1.14 (WAKEUP)
/~CS: R4.2, U1.12 (~CS)
GND: C2.2, C3.2, C4.2, C5.2, C6.1, D1.2, J6.1, Q1.1 (S), Q1.2 (S), Q1.3 (S), R6.2, R8.1, R9.2, R20.2, R21.1, U1.21 (GND), U1.24 (LSRC), U1.49 (GND); also elsewhere on the board
unnamed: C7.1, R21.2
unnamed: R7.2, S1.1, S1.2

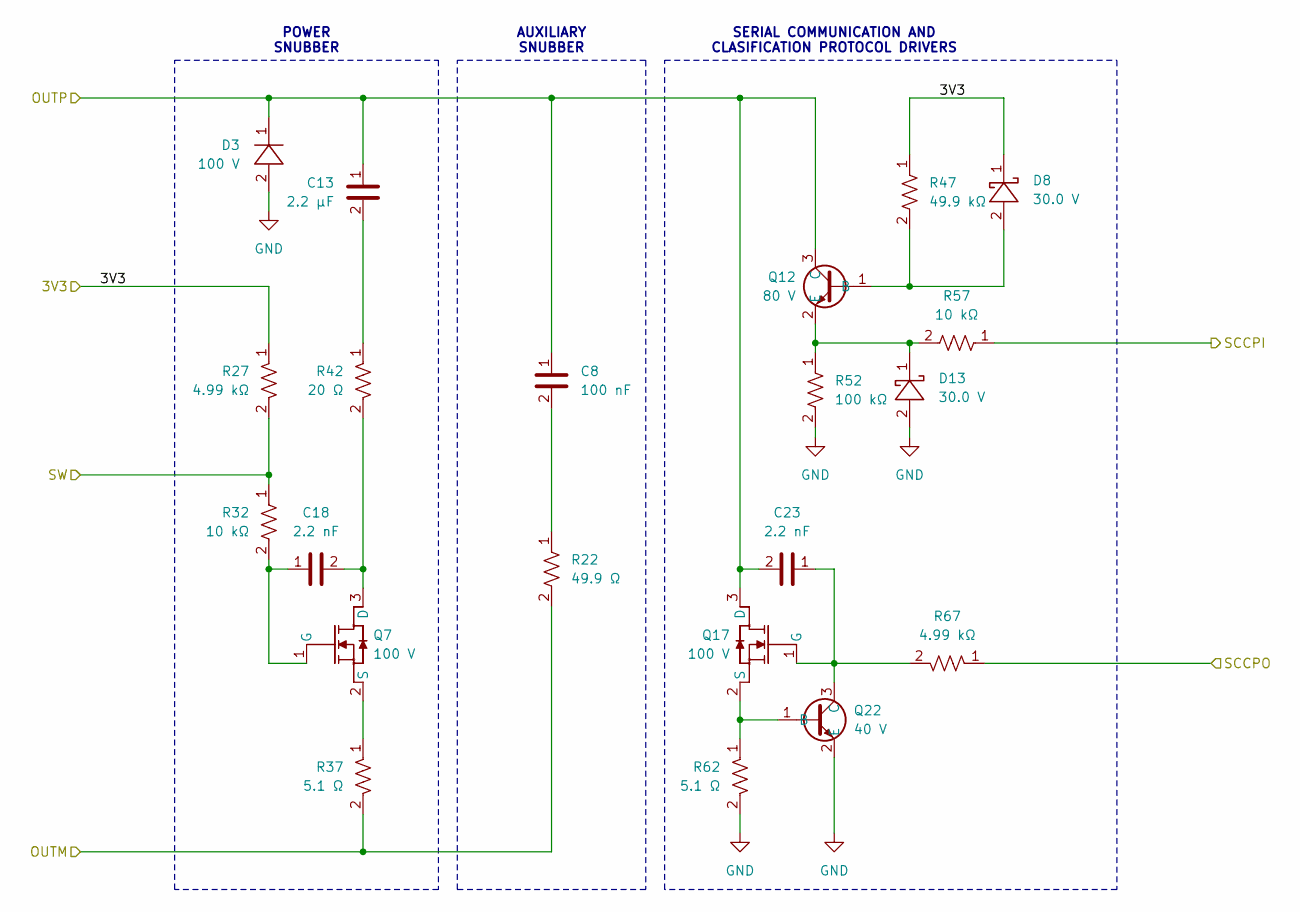
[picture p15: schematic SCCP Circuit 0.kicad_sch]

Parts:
C8: 100 nF; C_0603_1608Metric; Tolerance 10%; Voltage Rating 100V; MPN C1608X7S2A104K080AB
C13: 2.2 µF; C_0805_2012Metric; Tolerance 10%; Voltage Rating 100V; MPN CGA4J1X7R2A225K125AC
C18, C23: 2.2 nF; C_0402_1005Metric; Tolerance 10%; Voltage Rating 100V; MPN C1005X7S2A222K050BB
D3: 100 V; SMA; MPN S1B-13-F
D8, D13: 30.0 V; SOD323F; MPN BAT54WS-7-F
Q7, Q17: 100 V; SOT-323; MPN BSS123WQ-7-F
Q12: 80 V; SOT23-3; MPN MMBTA06-7-F
Q22: 40 V; SOT23-3; MPN MMBT3904LT3G
R22: 49.9 Ω; R_0603_1608Metric; Tolerance 1%; Voltage Rating 75V; MPN ERJ-3EKF49R9V
R27, R67: 4.99 kΩ; R_0402_1005Metric; Tolerance 1%; Voltage Rating 50V; MPN ERJ-2RKF4991X
R32, R57: 10 kΩ; R_0402_1005Metric; Tolerance 1%; Voltage Rating 50V; MPN ERJ-2RKF1002X
R37, R62: 5.1 Ω; R_1206_3216Metric; Tolerance 1%; Voltage Rating 200V; MPN RT1206FRE075R1L
R42: 20 Ω; R_1206_3216Metric; Tolerance 1%; Voltage Rating 200V; MPN RT1206FRE0720RL
R47: 49.9 kΩ; R_0402_1005Metric; Tolerance 1%; Voltage Rating 50V; MPN ERJ-2RKF4992X
R52: 100 kΩ; R_0402_1005Metric; Tolerance 1%; Voltage Rating 50V; MPN ERJ-2RKF1003X

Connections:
/3V3: D8.1, R27.1, R47.1; also elsewhere on the board
/OUTM0: R22.2, R37.2; also elsewhere on the board
/OUTP0: C8.1, C13.1, C23.2, D3.1, Q12.3 (C), Q17.3 (D); also elsewhere on the board
/SCCPI_0: R57.1
/SCCPO_0: R67.1
/SW0: R27.2, R32.1; also elsewhere on the board
GND: D3.2, D13.2, Q22.2 (E), R52.2, R62.2; also elsewhere on the board
unnamed: C8.2, R22.1
unnamed: C13.2, R42.1
unnamed: C18.2, Q7.3 (D), R42.2
unnamed: C18.1, Q7.1 (G), R32.2
unnamed: Q7.2 (S), R37.1
unnamed: D8.2, Q12.1 (B), R47.2
unnamed: D13.1, Q12.2 (E), R52.1, R57.2
unnamed: C23.1, Q17.1 (G), Q22.3 (C), R67.2
unnamed: Q17.2 (S), Q22.1 (B), R62.1

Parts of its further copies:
C9, C10, C11, C12: 100 nF; C_0603_1608Metric; Tolerance 10%; Voltage Rating 100V; MPN C1608X7S2A104K080AB
C14, C15, C16, C17: 2.2 µF; C_0805_2012Metric; Tolerance 10%; Voltage Rating 100V; MPN CGA4J1X7R2A225K125AC
C19, C20, C21, C22, C24, C25, C26, C27: 2.2 nF; C_0402_1005Metric; Tolerance 10%; Voltage Rating 100V; MPN C1005X7S2A222K050BB
D4, D5, D6, D7: 100 V; SMA; MPN S1B-13-F
D9, D10, D11, D12, D14, D15, D16, D17: 30.0 V; SOD323F; MPN BAT54WS-7-F
Q8, Q9, Q10, Q11, Q18, Q19, Q20, Q21: 100 V; SOT-323; MPN BSS123WQ-7-F
Q13, Q14, Q15, Q16: 80 V; SOT23-3; MPN MMBTA06-7-F
Q23, Q24, Q25, Q26: 40 V; SOT23-3; MPN MMBT3904LT3G
R23, R24, R25, R26: 49.9 Ω; R_0603_1608Metric; Tolerance 1%; Voltage Rating 75V; MPN ERJ-3EKF49R9V
R28, R29, R30, R31, R68, R69, R70, R71: 4.99 kΩ; R_0402_1005Metric; Tolerance 1%; Voltage Rating 50V; MPN ERJ-2RKF4991X
R33, R34, R35, R36, R58, R59, R60, R61: 10 kΩ; R_0402_1005Metric; Tolerance 1%; Voltage Rating 50V; MPN ERJ-2RKF1002X
R38, R39, R40, R41, R63, R64, R65, R66: 5.1 Ω; R_1206_3216Metric; Tolerance 1%; Voltage Rating 200V; MPN RT1206FRE075R1L
R43, R44, R45, R46: 20 Ω; R_1206_3216Metric; Tolerance 1%; Voltage Rating 200V; MPN RT1206FRE0720RL
R48, R49, R50, R51: 49.9 kΩ; R_0402_1005Metric; Tolerance 1%; Voltage Rating 50V; MPN ERJ-2RKF4992X
R53, R54, R55, R56: 100 kΩ; R_0402_1005Metric; Tolerance 1%; Voltage Rating 50V; MPN ERJ-2RKF1003X

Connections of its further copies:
/3V3: D9.1, D10.1, D11.1, D12.1, R28.1, R29.1, R30.1, R31.1, R48.1, R49.1, R50.1, R51.1; also elsewhere on the board
/OUTM1: R23.2, R38.2; also elsewhere on the board
/OUTM2: R24.2, R39.2; also elsewhere on the board
/OUTM3: R25.2, R40.2; also elsewhere on the board
/OUTM4: R26.2, R41.2; also elsewhere on the board
/OUTP1: C9.1, C14.1, C24.2, D4.1, Q13.3 (C), Q18.3 (D); also elsewhere on the board
/OUTP2: C10.1, C15.1, C25.2, D5.1, Q14.3 (C), Q19.3 (D); also elsewhere on the board
/OUTP3: C11.1, C16.1, C26.2, D6.1, Q15.3 (C), Q20.3 (D); also elsewhere on the board
/OUTP4: C12.1, C17.1, C27.2, D7.1, Q16.3 (C), Q21.3 (D); also elsewhere on the board
/SCCPI_1: R58.1
/SCCPI_2: R59.1
/SCCPI_3: R60.1
/SCCPI_4: R61.1
/SCCPO_1: R68.1
/SCCPO_2: R69.1
/SCCPO_3: R70.1
/SCCPO_4: R71.1
/SW1: R28.2, R33.1; also elsewhere on the board
/SW2: R29.2, R34.1; also elsewhere on the board
/SW3: R30.2, R35.1; also elsewhere on the board
/SW4: R31.2, R36.1; also elsewhere on the board
GND: D4.2, D5.2, D6.2, D7.2, D14.2, D15.2, D16.2, D17.2, Q23.2 (E), Q24.2 (E), Q25.2 (E), Q26.2 (E), R53.2, R54.2, R55.2, R56.2, R63.2, R64.2, R65.2, R66.2; also elsewhere on the board
unnamed: C9.2, R23.1
unnamed: C10.2, R24.1
unnamed: C11.2, R25.1
unnamed: C12.2, R26.1
unnamed: C14.2, R43.1
unnamed: C15.2, R44.1
unnamed: C16.2, R45.1
unnamed: C17.2, R46.1
unnamed: C19.2, Q8.3 (D), R43.2
unnamed: C19.1, Q8.1 (G), R33.2
unnamed: Q8.2 (S), R38.1
unnamed: C20.2, Q9.3 (D), R44.2
unnamed: C20.1, Q9.1 (G), R34.2
unnamed: Q9.2 (S), R39.1
unnamed: C21.2, Q10.3 (D), R45.2
unnamed: C21.1, Q10.1 (G), R35.2
unnamed: Q10.2 (S), R40.1
unnamed: C22.2, Q11.3 (D), R46.2
unnamed: C22.1, Q11.1 (G), R36.2
unnamed: Q11.2 (S), R41.1
unnamed: D9.2, Q13.1 (B), R48.2
unnamed: D14.1, Q13.2 (E), R53.1, R58.2
unnamed: D10.2, Q14.1 (B), R49.2
unnamed: D15.1, Q14.2 (E), R54.1, R59.2
unnamed: D11.2, Q15.1 (B), R50.2
unnamed: D16.1, Q15.2 (E), R55.1, R60.2
unnamed: D12.2, Q16.1 (B), R51.2
unnamed: D17.1, Q16.2 (E), R56.1, R61.2
unnamed: C24.1, Q18.1 (G), Q23.3 (C), R68.2
unnamed: Q18.2 (S), Q23.1 (B), R63.1
unnamed: C25.1, Q19.1 (G), Q24.3 (C), R69.2
unnamed: Q19.2 (S), Q24.1 (B), R64.1
unnamed: C26.1, Q20.1 (G), Q25.3 (C), R70.2
unnamed: Q20.2 (S), Q25.1 (B), R65.1
unnamed: C27.1, Q21.1 (G), Q26.3 (C), R71.2
unnamed: Q21.2 (S), Q26.1 (B), R66.1

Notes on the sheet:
POWER SNUBBER
SERIAL COMMUNICATION AND CLASIFICATION PROTOCOL DRIVERS
AUXILIARY SNUBBER

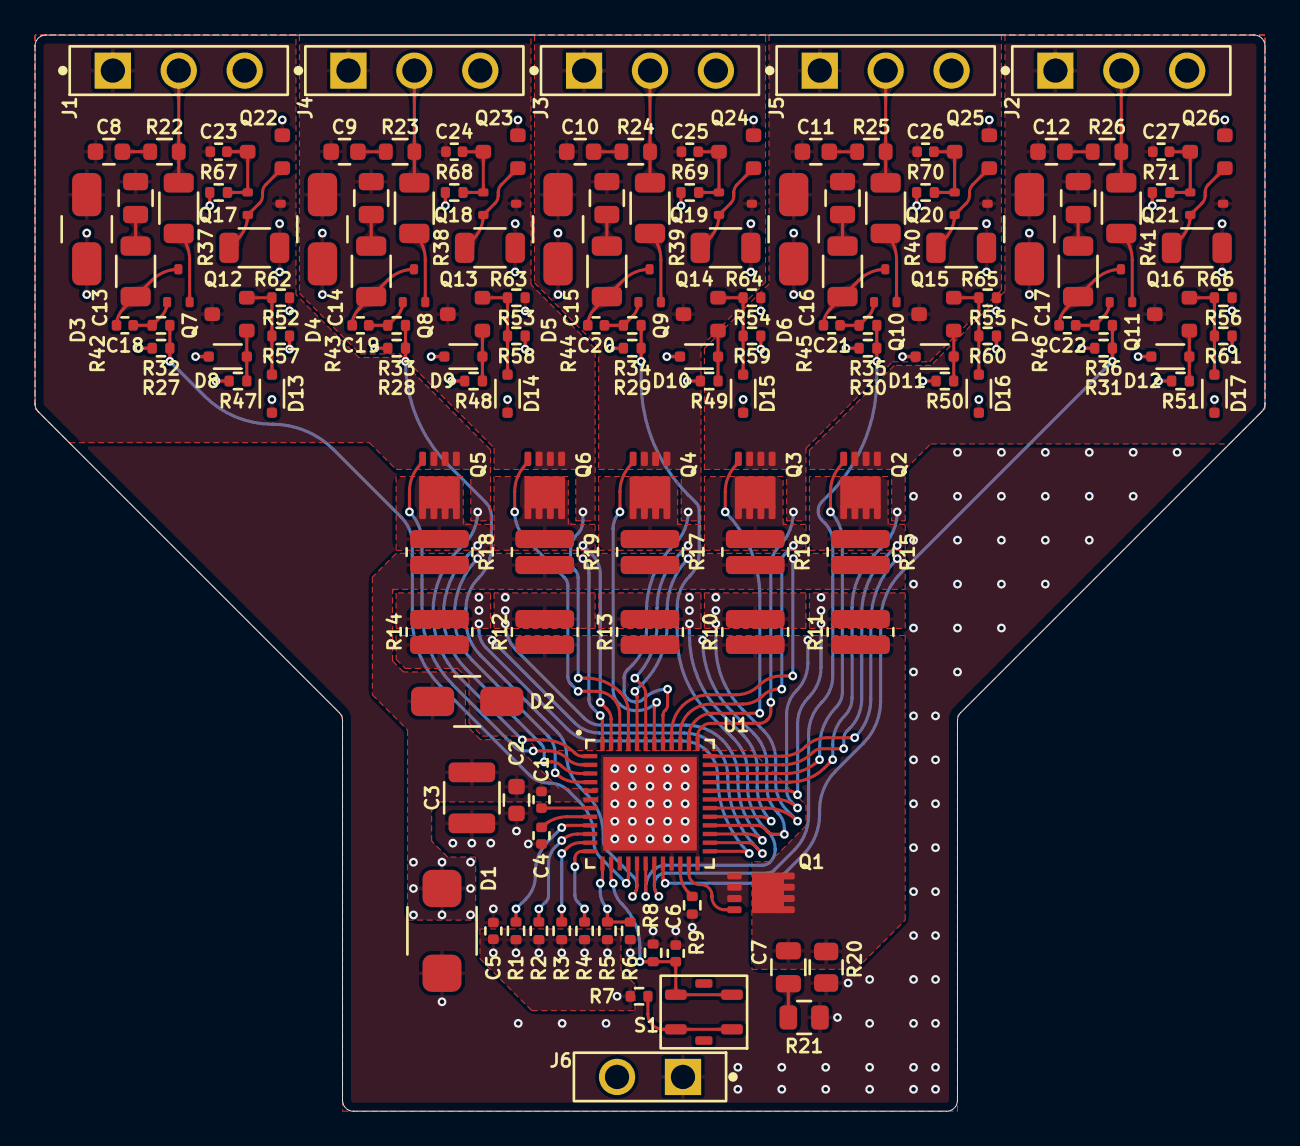
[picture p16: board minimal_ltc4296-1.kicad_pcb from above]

Board: 4 copper layers, 71.1 x 62.2 mm, 149 parts (0 on the bottom side), 86 nets.

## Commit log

2026-01-31 Add KiCad project files for minimal LTC4296-1 board
    [minimal_ltc4296-1.kicad_pcb, minimal_ltc4296-1.kicad_sch]
2026-01-31 Add KiCad Symbols Generator submodule
2026-01-31 Add KiCad library tables (fp-lib-table and sym-lib-table)
2026-01-31 Update KiCad project files (PCB layout, schematic, and project settings)
    [minimal_ltc4296-1.kicad_pcb, minimal_ltc4296-1.kicad_sch]
2026-01-31 chore: update workflows and kicad config from central repository
2026-01-31 Update KiCad documentation for minimal_ltc4296-1 (schematics and PCB renders)
2026-01-31 Update KiCad project files
    [minimal_ltc4296-1.kicad_pcb]
2026-01-31 Update KiCAD project files and generator
    [minimal_ltc4296-1.kicad_pcb, minimal_ltc4296-1.kicad_sch]
2026-01-31 Update KiCAD Symbols Generator
2026-02-01 Update KiCAD files and submodule
    [minimal_ltc4296-1.kicad_pcb, minimal_ltc4296-1.kicad_sch]
2026-02-01 Update KiCAD Symbols Generator submodule
2026-02-03 Update KiCAD schematic and PCB files
    [minimal_ltc4296-1.kicad_pcb, minimal_ltc4296-1.kicad_sch]
2026-02-04 Update PCB and schematic files
    [minimal_ltc4296-1.kicad_pcb, minimal_ltc4296-1.kicad_sch]
2026-02-05 Update KiCad PCB and schematic files
    [minimal_ltc4296-1.kicad_pcb, minimal_ltc4296-1.kicad_sch]
2026-02-06 Update PCB file
    [minimal_ltc4296-1.kicad_pcb]
2026-02-07 Update KiCAD files and generator
    [minimal_ltc4296-1.kicad_pcb, minimal_ltc4296-1.kicad_sch]
2026-02-07 Update PCB layout and schematic, refresh symbol library
    [minimal_ltc4296-1.kicad_pcb, minimal_ltc4296-1.kicad_sch]
2026-02-08 Update PCB layout and schematic
    [minimal_ltc4296-1.kicad_pcb, minimal_ltc4296-1.kicad_sch]
2026-02-08 Update PCB layout
    [minimal_ltc4296-1.kicad_pcb]
2026-02-09 Update PCB and schematic files, and KiCAD symbols generator
    [minimal_ltc4296-1.kicad_pcb, minimal_ltc4296-1.kicad_sch]
2026-02-11 Update KiCad PCB file
    [minimal_ltc4296-1.kicad_pcb]
2026-02-14 Update KiCad project settings and PCB layout
    [minimal_ltc4296-1.kicad_pcb]
2026-02-17 Update KiCad project files and add SCCP Circuit 0 schematic
    [SCCP Circuit 0.kicad_sch, minimal_ltc4296-1.kicad_pcb, minimal_ltc4296-1.kicad_sch]
2026-02-19 Update KiCad schematic, PCB, and symbol libraries with SCCP circuit changes
    [SCCP Circuit 0.kicad_sch, minimal_ltc4296-1.kicad_pcb, minimal_ltc4296-1.kicad_sch]
2026-02-19 Update KiCAD_Symbols_Generator submodule
2026-02-21 Update KiCad config zoom and pan settings
2026-02-21 Update KiCad config pan setting
2026-03-03 Add all PCB view images to README
